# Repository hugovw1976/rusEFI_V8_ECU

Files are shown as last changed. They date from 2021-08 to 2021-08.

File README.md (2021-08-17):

# rusEFI_V8_ECU

- 8x 3A low-side drivers
- 4x 10A low_side drivers
- 8x 5v ignition or general purpose outputs (or 4 igniters/ 4general purpose otputs)
- One H-bridge for electronic throttle
- 10x Analog voltage inputs
- 4x Analog temperature (5v pullup) inputs
- 2x VR crank/cam/vehicle speed inputs
- 6x hall cam/crank or digital input (-2 if VR sensors used)
- Base on proteus board (intended for use with proteus firmware microcontroller, pin matched to correspond output)

rusEFI project: https://github.com/rusefi/rusefi
Proteus project: https://github.com/mck1117/proteus

Please do not use the gerber files, the board is not tested yet!
P&P file not tested on JLC PCB (Board is hand soldering)

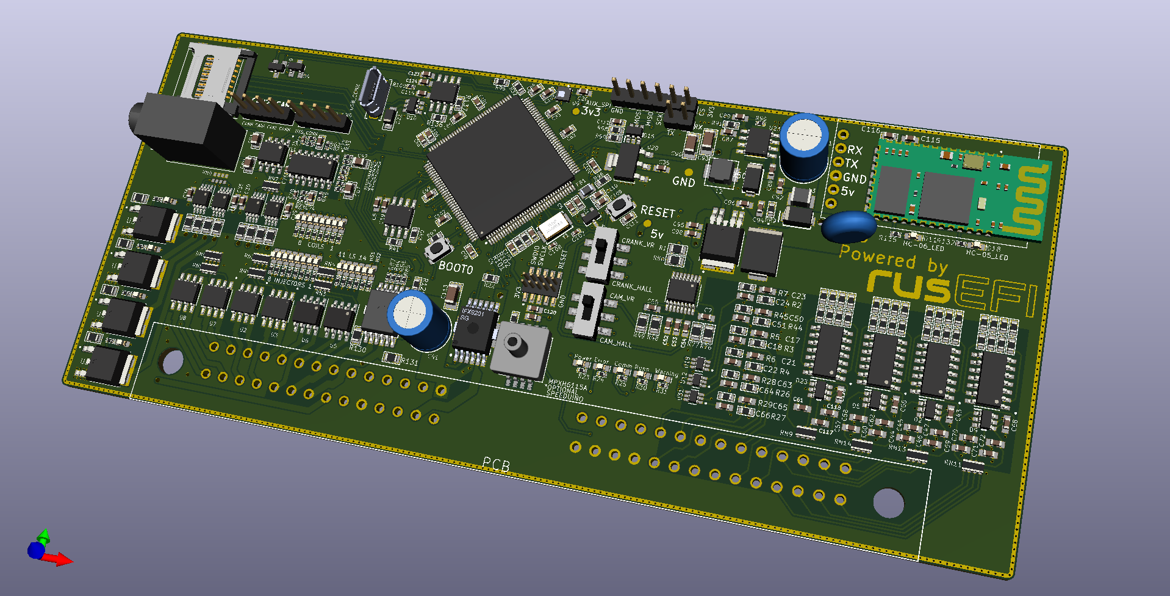
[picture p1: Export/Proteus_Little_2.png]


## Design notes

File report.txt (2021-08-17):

Cambiar footprint "D21" (from "Proteus_Little:SOD-123FL") to "Proteus_Little:SOD-123FL": OK
Cambiar footprint "D20" (from "Proteus_Little:SOD-123FL") to "Proteus_Little:SOD-123FL": OK
Cambiar footprint "D17" (from "Proteus_Little:SOD-123FL") to "Proteus_Little:SOD-123FL": OK
Cambiar footprint "D16" (from "Proteus_Little:SOD-123FL") to "Proteus_Little:SOD-123FL": OK

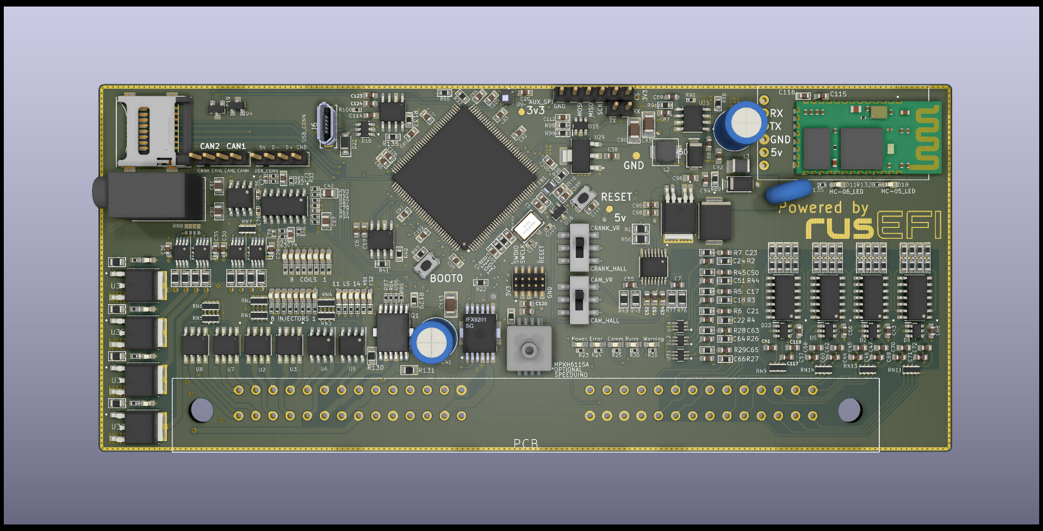
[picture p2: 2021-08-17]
Export/Proteus_Little_5.png

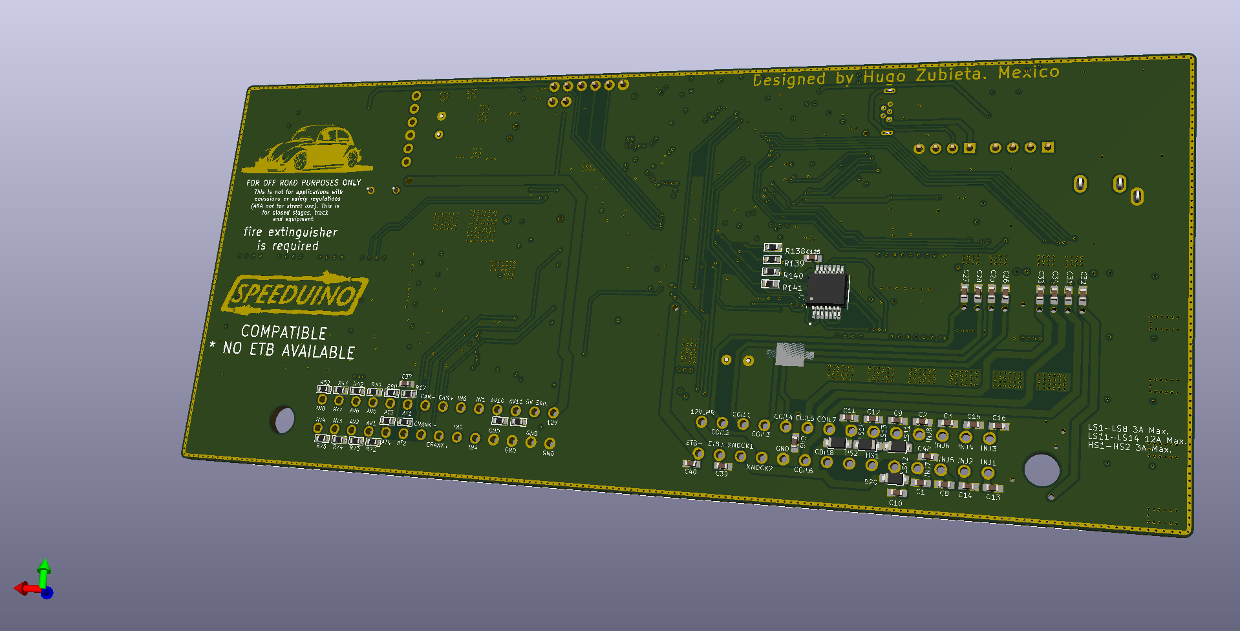
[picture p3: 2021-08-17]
Export/Proteus_Little_4.png

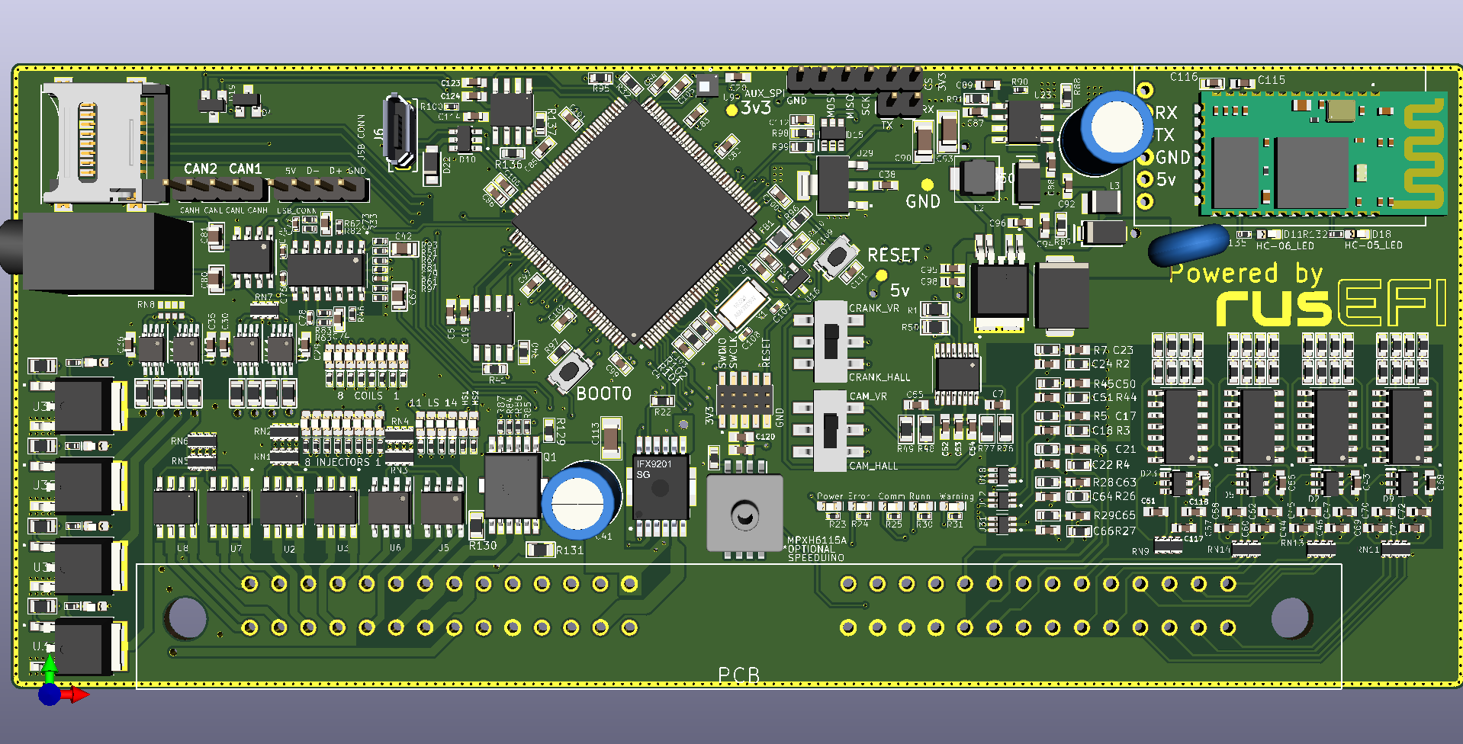
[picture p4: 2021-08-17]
Export/Proteus_Little_1.png

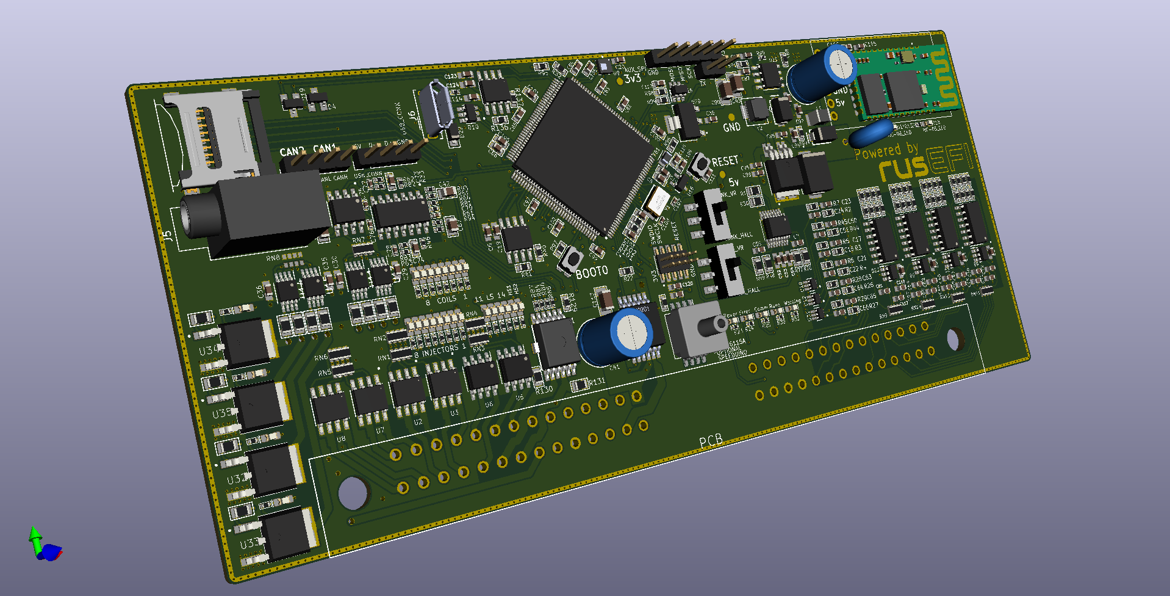
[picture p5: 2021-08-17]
Export/Proteus_Little_3.png

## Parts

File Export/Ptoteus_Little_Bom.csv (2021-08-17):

Qty | Value | Device | Package | LCSC PART # | MOUSER PART # | Parts
1 | B72530T6170K062 | VARISTOR-5 | R-5 | C693526 |  | R47
5 | 100K | SMD-RES-100K-1%-1/16W(0402) | R0402 | C25741 |  | R51, R61, R62, R63, R100
8 | 100R | SMD-RES-100R-5%-1/8W(0805) | R0805 | C441975 |  | R8, R9, R10, R11, R12, R13, R14, R15
4 | 10K | 4R-N0603-ARC | 0603-ARC | C29718 |  | RN9, RN11, RN13, RN14
2 | 10K | SMD-RES-10K-1%-1/16W(0402) | R0402 | C25744 |  | R84, R85
29 | 10K | SMD-RES-10K-1%-1/10W(0603) | R0603 | C323556 |  | R18, R19, R20, R21, R22, R40, R53, R54, R55, R56, R65, R67, R78, R79, R88, R96, R97, R98, R101, R102, R137, R138, R139, R140, R141, R147, R148, R149, R150
6 | 10K | SMD-RES-10K-1%-1/4W(0805) | R0805 | C161788 |  | R1, R48, R49, R50, R76, R77
2 | 15K | SMD-RES-15K-1%-1/16W(0402) | R0402 | C25756 |  | R86, R87
1 | 150R | SMD-RES-150-1%-1/4W(0805) | R0805 | C365244 |  | R129
2 | 4.7K | SMD-RES-4.7K-1%-1/4W(0805) | R0805 | C363267 |  | R130,R131
2 | 120R | SMD-RES-120R-5%-1/10W(0603) | R0603 | C22787 |  | R41, R136
8 | 1K | 4R-N0603-ARC | 0603-ARC | C20197 |  | RN1, RN2, RN3, RN4, RN5, RN6, RN7, RN8
3 | 12K | SMD-RES-12K-1%-1/16W(0402) | R0402 | C102781 |  | R33, R46, R90
1 | 1R | SMD-RES-1R-5%-1/10W(0603) | R0603 | C22936 |  | R89
8 | 2.2K | SMD-RES-2.2K-5%-1/10W(0603) | R0603 | C4190 |  | R2, R3, R4, R26, R27, R32, R44, R95
4 | 2.7K | SMD-RES-2.7K-1%-1/10W(0603) | R0603 | C328353 |  | R16, R17, R34, R80
2 | 22K | SMD-RES-22R-1%-1/16W(0402) | R0402 | C25768 |  | R64, R81
6 | 3.3K | SMD-RES-3.3K-1%-1/10W(0603) | R0603 | C22978 |  | R5, R6, R7, R28, R29, R45
33 | 330R | SMD-RES-330R-1%-1/16W(0402) | R0402 | C328315 |  | R23, R24, R25, R30, R31, R103, R104, R105, R106, R107, R108, R109, R110, R111, R112, R113, R114, R115, R116, R117, R118, R119, R120, R121, R122, R123, R124, R125, R126, R127, R128, R132, R135
4 | 330R | SMD-RES-330R-1%-1/8W(0805) | R0805 | C441945 |  | R1020, R1021, R1022, R1023
2 | 33K | SMD-RES-33K-1%-1/16W(0402) | R0402 | C25779 |  | R82, R83
11 | 470K | SMD-RES-470K-1%-1/10W(0603) | R0603 | C23178 |  | R39, R42, R43, R52, R66, R72, R73, R74, R75, R92, R133
2 | 470K | SMD-RES-470K-1%-1/16W(0402) | R0402 | C25790 |  | R93, R94
16 | 5.6K | SMD-RES-5.6K-1%-1/10W(0603) | R0603 | C114627 |  | R35, R36, R37, R38, R57, R58, R59, R60, R68, R69, R70, R71, R143, R144, R145, R146
1 | 68K | SMD-RES-68K-1%-1/10W(0603) | R0603 | C23231 |  | R91
1 | 82k | SMD-RES-82K-1%-1/10W(0603) | R0603 | C23254 |  | R99
8 | 1.0uF | 1uF ±10% 50V X7R 0603 | C0603 | C525334 |  | C6, C53, C92, C95, C96, C112, C116, C119, C120, C123
28 | 100nF | 100nF ±10% 50V X7R 0603 | C0603 | C14663 |  | C19, C20, C29, C30, C35, C36, C37, C44, C45, C46, C47, C52, C57, C58, C60, C61, C62, C69, C70, C71, C72, C88, C114, C115, C117, C118, C124, C125
38 | 10nF | 10nF ±10% 50V X7R 0603 | C0603 | C57112 |  | C1, C2, C3, C4, C5 C8, C9, C10, C11, C12, C13, C14, C15, C16, C25, C26, C27, C28, C31, C32, C33, C34, C39, C40, C48, C49, C54, C82, C83, C84, C85, C86,C87, C97, C99, C104, C109, C111
1 | 10nf | CERAMIC-10NF-50V-10%-X7R(0402) | C0402 | C15195 |  | C79
2 | 10uf | 10uF ±10% 16V X7R 0805 | C0805 | C95841 |  | C80, C81
3 | 10uf | 10uF ±10% 25V X7R 1206 | C1206 | C14860 |  | C90, C93, C113
14 | 1nF | 1nF ±10% 50V X7R 0603 | C0603 | C1588 |  | C7, C17, C18, C21, C22, C23, C24, C50, C51, C55, C63, C64, C65, C66
2 | 2.2uf | 2.2uF ±10% 25V X7R 0603 | C0603 | C99228 |  | C105, C106
1 | 22uf | 22uF ±20% 10V X5R 0603 | C0603 | C84419 |  | C98
1 | 270PF | 270pF ±10% 50V X7R 0603 | C0603 | C1608 |  | C89
2 | 3.3nf | 3.3nF ±10% 50V X7R 0805 | C0805 | C53175 |  | C42, C67
2 | 330PF 50V | 330pF ±5% 50V C0G 0402 | C0402 | C1535 |  | C77, C78
4 | 33nF | 33nF ±10% 50V X7R 0603 | C0603 | C21117 |  | C43, C56, C68, C118
2 | 33pf | 33pF ±5% 50V C0G 0402 | C0402 | C1562 |  | C107, C108
7 | 4.7uF | 4.7uF ±10% 35V X5R 0603 | C0603 | C329940 |  | C38, C94, C100, C101, C102, C103, C110
2 | 47PF | 47pF ±5% 50V C0G 0402 | C0402 | C1567 |  | C75, C76
2 | 680pf | 680pF ±10% 50V X7R 0603 | C0603 | C1630 |  | C73, C74
2 | 56uF | CPOL-USE3.5-8 | E3,5-8 |  | 667-EEH-AZF1H560 | C41, C91
1 | 10U | 10uH ±20% 3.2A 125mΩ SMD,5.2x5.4x3.0mm | 0503 | C139506 |  | L2
1 | 2.2U | 2.2uH ±5% 320mA 1Ω 1210 Inductors | 1210 | C36828 |  | L3
3 | 74HC2G17 | Dual non-inverting Schmitt trigger | SOT-363_SC-70-6 | C94189 |  | U12, U18, U31
1 | AMS1117-3.3 | AMS1117-3.3 | SOT-223 | C6186 |  | U29
2 | SMA_DIODE | Schottky Barrier Diodes 40V 3A 500mV @ 3A | SMA(DO-214AC) | C85098 |  | D12, D13
4 | DSS34 | DIODE_SOD-123FL | SOD-123FL | C511866 |  | D16, D17, D20, D21
1 | B5819W | Schottky Barrier Diodes | SOD-123FL | C8598 |  | D22
2 | PESD1CAN | PESD1CAN | SOT23 | C343993 |  | D4, D11
1 | SM15T33CA | BIDIRECTIONAL TVS | SMC(DO-214AB) | C133707 |  | D3
5 | SRV05-4.TCT | SRV05-4.TCT | SOT-23-6 | C85364 |  | D2, D5, D9, D15, D23
1 | USBLC6-2SC6 | SOT-23-6 Diodes | SOT-23-6 | C7519 |  | D10
1 | Yellow | LED-YELLOW0603 | LED-0603 | C84268 |  | D14
29 | Blue | LED-BLUE0603 | LED-0603 | C72041 |  | D8, D11, D18, D27, D28, D29, D30, D31, D32, D33, D34, D35, D36, D37, D38, D39, D40, D41, D42, D43, D44, D45, D46, D47, D48, D49, D50, D51, D52
1 | Red | LED-RED0603 | LED-0603 | C72044 |  | D1
2 | Green | LED-GREEN0603 | LED-0603 | C72043 |  | D6, D7
2 | K3-2235S-F1 | DPDT On-On SMD Toggle Switches | SW_JS202011SCQN | C223858 |  | S1, S3
2 | KMR221GLFS | SPST_SMD Tactile Switches | SMD 4.6x2.8 | C72443 |  | SW1, SW2
4 | ISL9V3040D3ST | Ignition IGBT | TO-252AA | C462128 |  | U32, U33, U34, U35
1 | LMR14020SDDAR | 40V 2A DC-DC Converters | SO PowerPAD-8 | C187824 |  | U23
1 | LPS25HBTR | Pressure Sensors | HLGA-10L | C87898 |  | U9
1 | MAX9926UAEE/V+ | Sensor Interface ICs | QSOP-16 | C2678421 |  | U19
1 | MCP6002T-E/MS | Low Power OpAmps | SOIC-8_150mil | C7377 |  | U$1
5 | MCP6004T | Low Power OpAmps | SOIC-14 | C7378 |  | U17, U22, U25, U28
4 | MIC4427YMM-TR | MIC4427YMM-TR | MSOP-8 | C144222 |  | U11, U13, U14, U15
1 | REF3033AIDBZR | Voltage References | SOT-23(SOT-23-3) | C36658 |  | U16
1 | STMICROELECTRONICS | STM32F429ZGT6 | LQFP-144_20x20x05P | C46525 |  | U20
1 | TLE4251DATMA1 | LDO Voltage Regulators | TO252-5 | C539669 |  | U21
1 | IFX9201SGAUMA1 | 6 A H-Bridge with SPI | SO-12 | C112633 |  | U10
2 | SN65HVD230DR | Transceiver CAN 1/1 1Mbps | SOIC-8_150mil | C12084 |  | U27, U30
1 | BTS5215L | MOSFET Gate Drivers | PG-DSO-12 | C386329 |  | Q1
4 | VNS3NV04PTR-E | MOSFET Gate Drivers | SO-8 | C146561 |  | U2, U3, U5, U6, U7, U8
1 | 8MHz ±10ppm 20pF 60Ω | SMD Crystal Resonators | SMD-5032_2P | C115962 |  | Y1
1 | FERRITE_BEAD | Ferrite Beads | F0805 | C1015 |  | FB1
1 | USB_CONN | U-D-M5DD-W-1 |  | C145795 |  | J6
1 | MPXH6115A | Pressure Sensor | SSOP-8 | ONLY FOR SPEEDUINO | 841-MPXH6115A6U | PS1
1 | SD_CONNECTOR | Connector microSD™ Memory Card 8 SMD |  | C125814 |  | J2
1 | AUDIO JACK 3.5MM | CUI DEVICES 3.5MM AUDIO JACK NO SWITCH |  |  | 490-SJ1-3533NG | J5
1 | 74HC125DB,112 | Quadruple Bus Buffer Gates | SSOP-14 | C507233 |  | U36
2 | VNLD5090TR-E | Low-side driver | SO-8 | C222209 |  | U5, U6

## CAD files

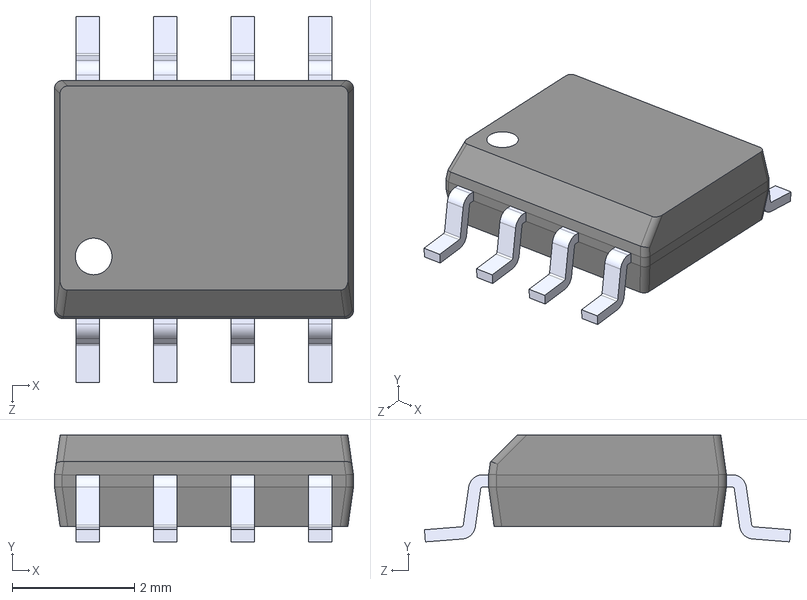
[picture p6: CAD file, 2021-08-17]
kicad-libraries-master/VNLD5090TR-E.step
4.90 x 1.75 x 6.00 mm

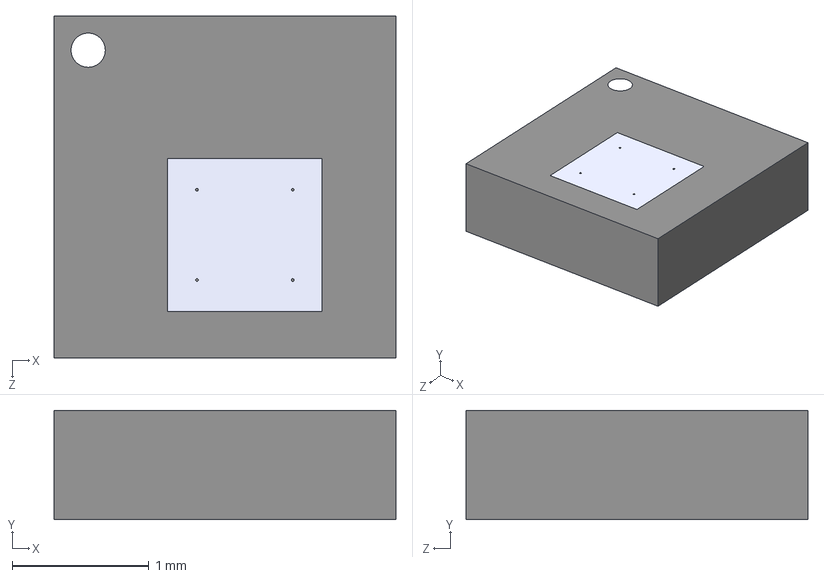
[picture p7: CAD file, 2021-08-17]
kicad-libraries-master/LPS25HBTR--3DModel-STEP-56544.STEP
2.50 x 0.8 x 2.50 mm

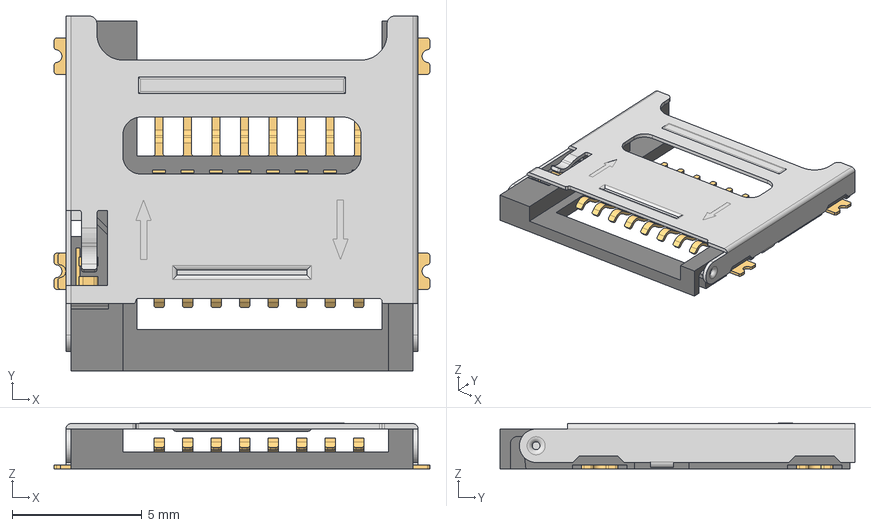
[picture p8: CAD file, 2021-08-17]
kicad-libraries-master/Micro_SD.stp
14.5 x 13.7 x 1.77 mm
693072010801_PIN x 8
693072010801_PATTE x 4
693072010801_CACHE
693072010801_PATTE_SPE

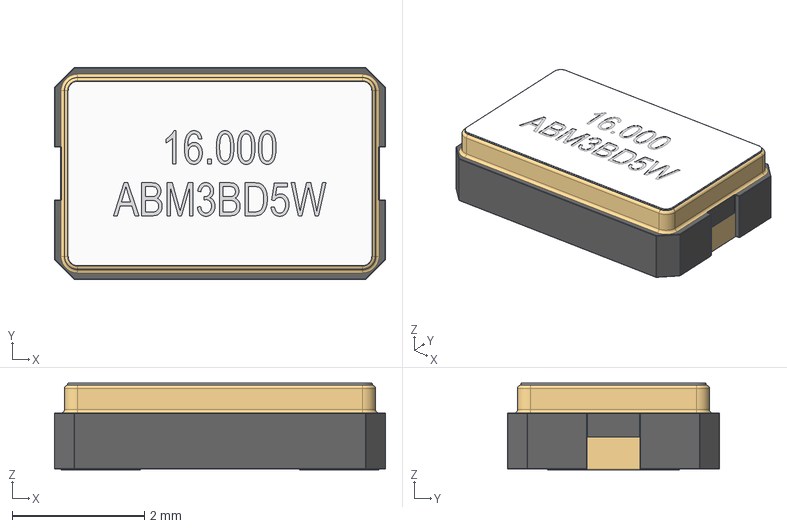
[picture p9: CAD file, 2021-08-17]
kicad-libraries-master/Crystal ABM3-16.000MHZ-B2-T.stp
5.00 x 3.20 x 1.31 mm

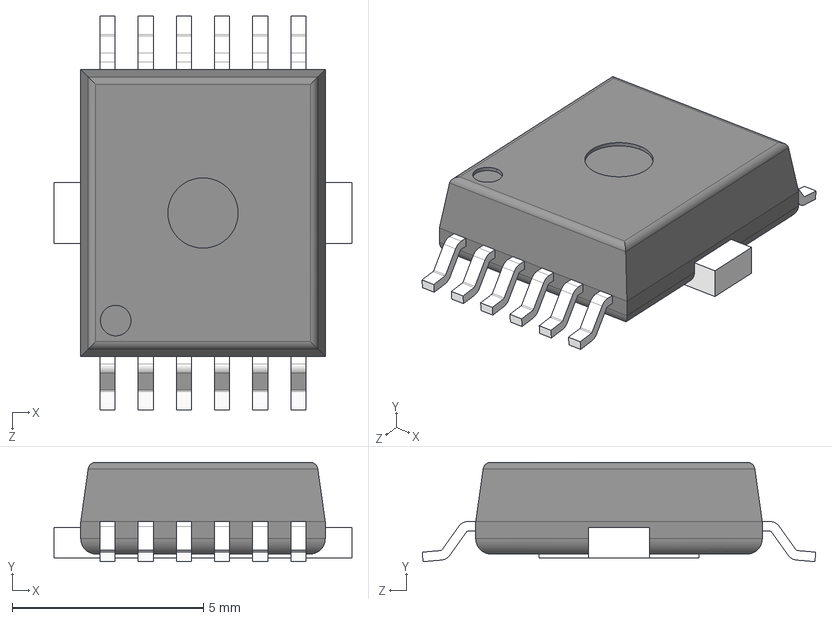
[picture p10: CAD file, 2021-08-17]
kicad-libraries-master/BTS5215L.step
7.80 x 2.60 x 10.3 mm

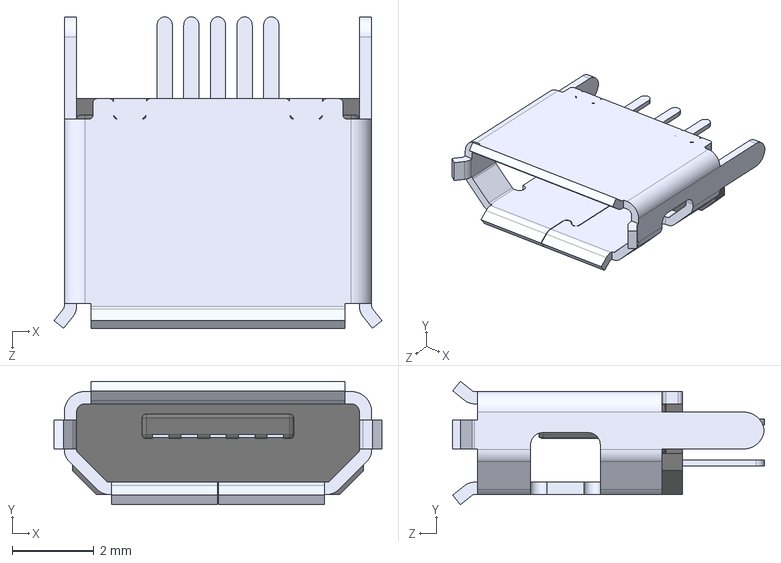
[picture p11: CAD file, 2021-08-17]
kicad-libraries-master/Micro usb_vetical.STEP
8.00 x 3.01 x 7.60 mm

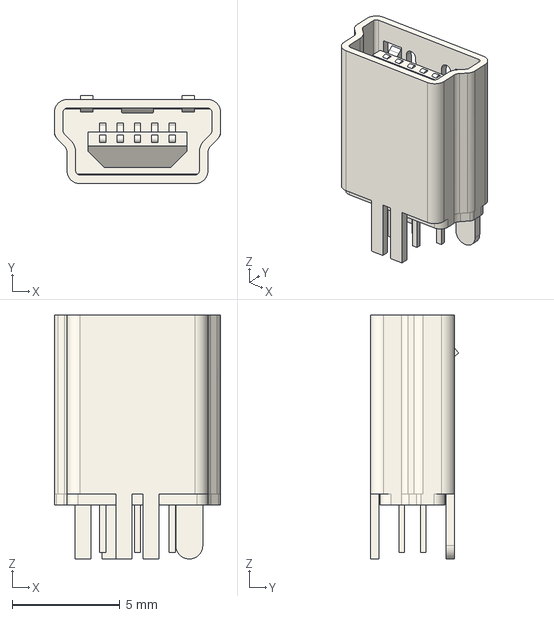
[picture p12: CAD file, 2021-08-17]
kicad-libraries-master/USB_Vert_C-1734753-1.step
7.70 x 4.09 x 11.3 mm

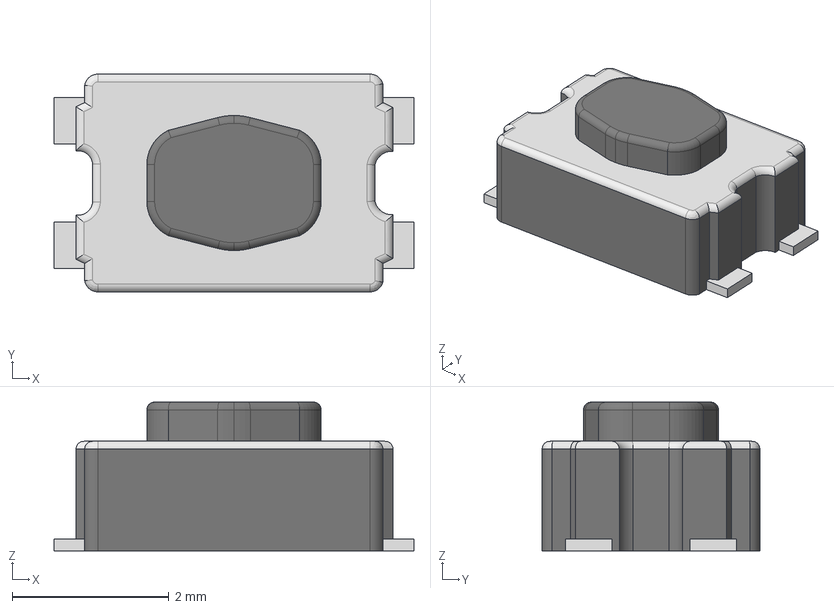
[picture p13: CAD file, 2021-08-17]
kicad-libraries-master/Switch_KMR621NG LFS.step
4.60 x 2.78 x 1.90 mm

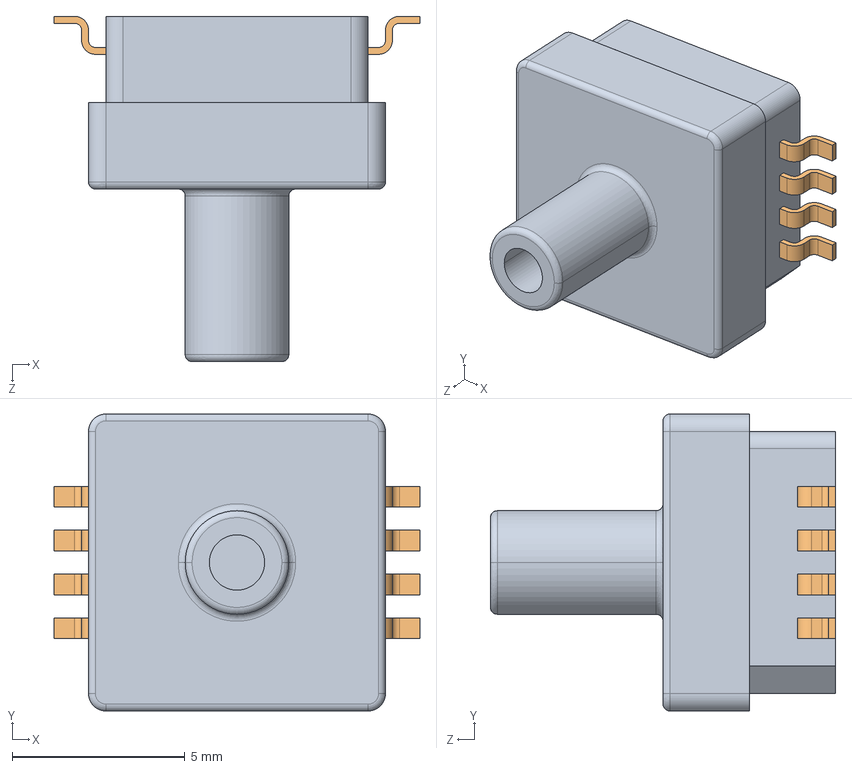
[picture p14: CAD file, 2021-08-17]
kicad-libraries-master/MPXH6115A.STEP
10.6 x 8.60 x 10.0 mm
Imported
Imported_2 x 8

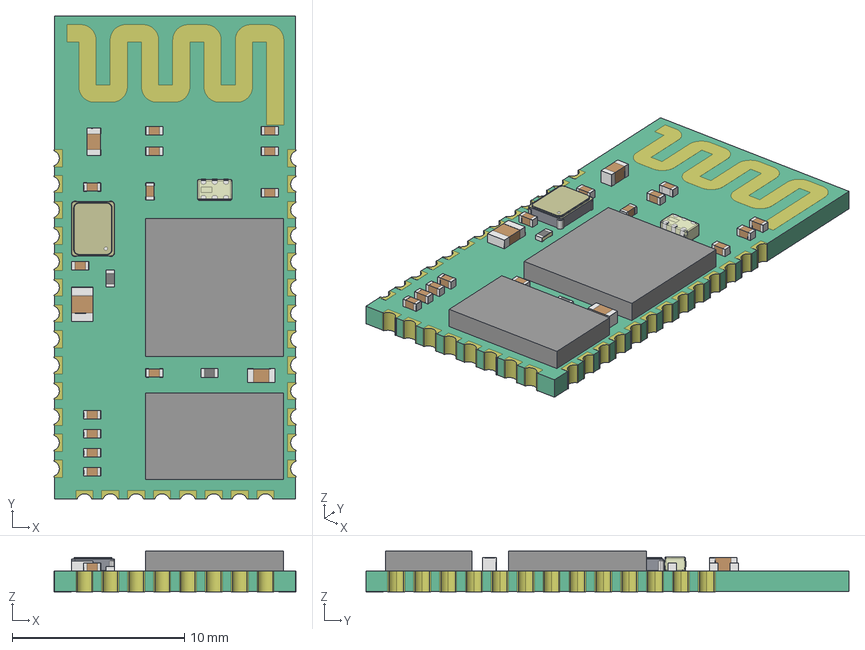
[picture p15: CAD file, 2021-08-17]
kicad-libraries-master/itead_hc-05.step
14.0 x 28.0 x 2.35 mm

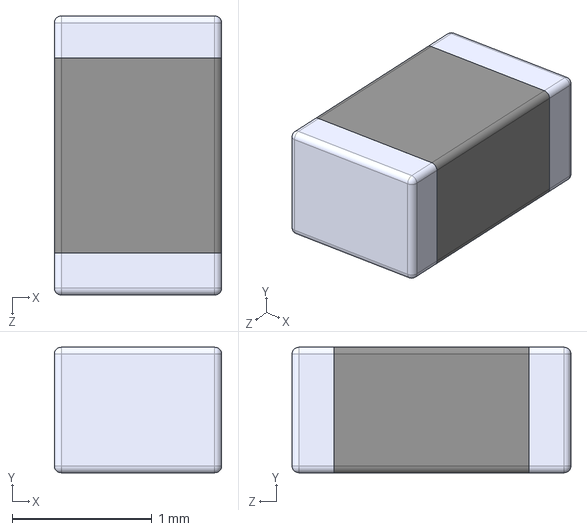
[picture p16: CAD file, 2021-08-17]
kicad-libraries-master/ferrite_bead_0805.STEP
1.20 x 0.9 x 2.00 mm

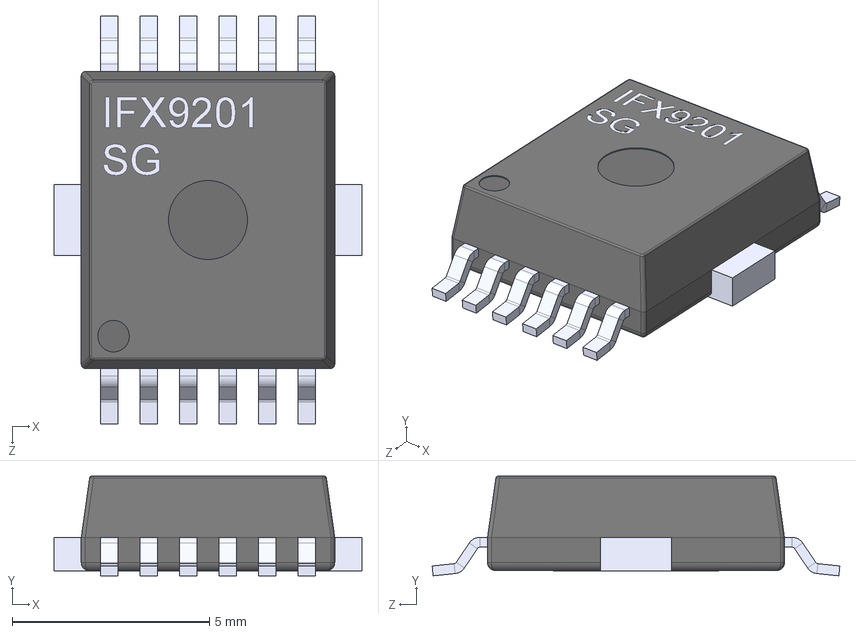
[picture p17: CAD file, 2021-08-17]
kicad-libraries-master/IFX9201SG-.STEP
7.80 x 2.52 x 10.3 mm

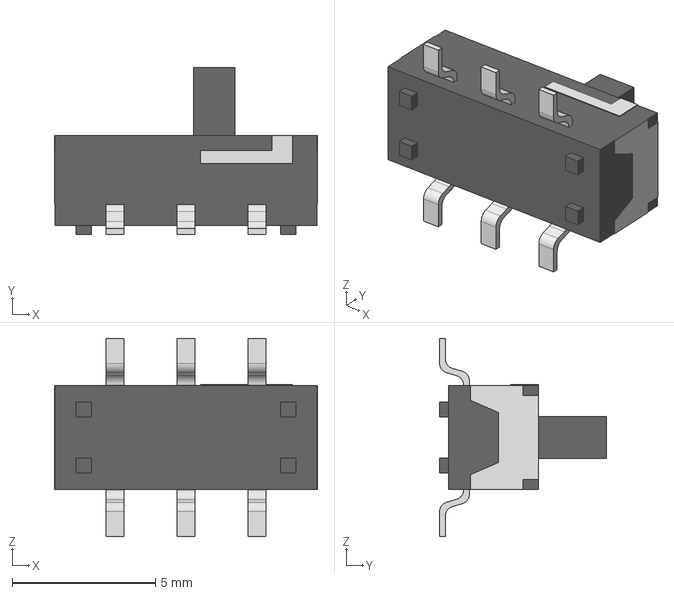
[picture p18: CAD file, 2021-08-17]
kicad-libraries-master/Selector Switch - MSS22D18.stp
9.17 x 5.82 x 6.91 mm

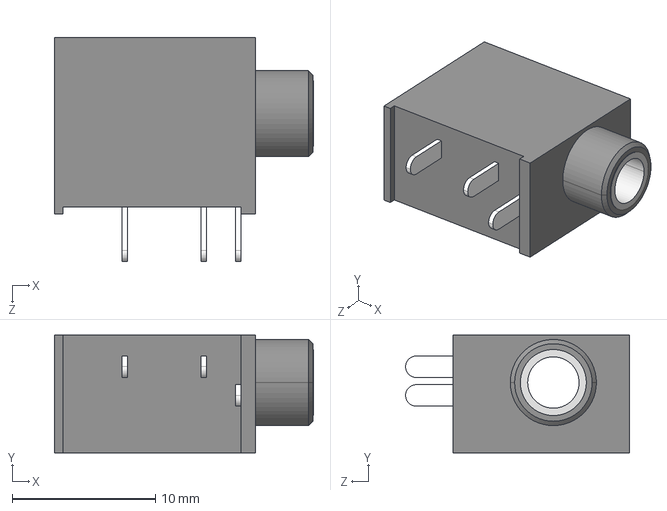
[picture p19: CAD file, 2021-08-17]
kicad-libraries-master/Audio_Jack_3.5mm.step
18.1 x 8.20 x 15.6 mm

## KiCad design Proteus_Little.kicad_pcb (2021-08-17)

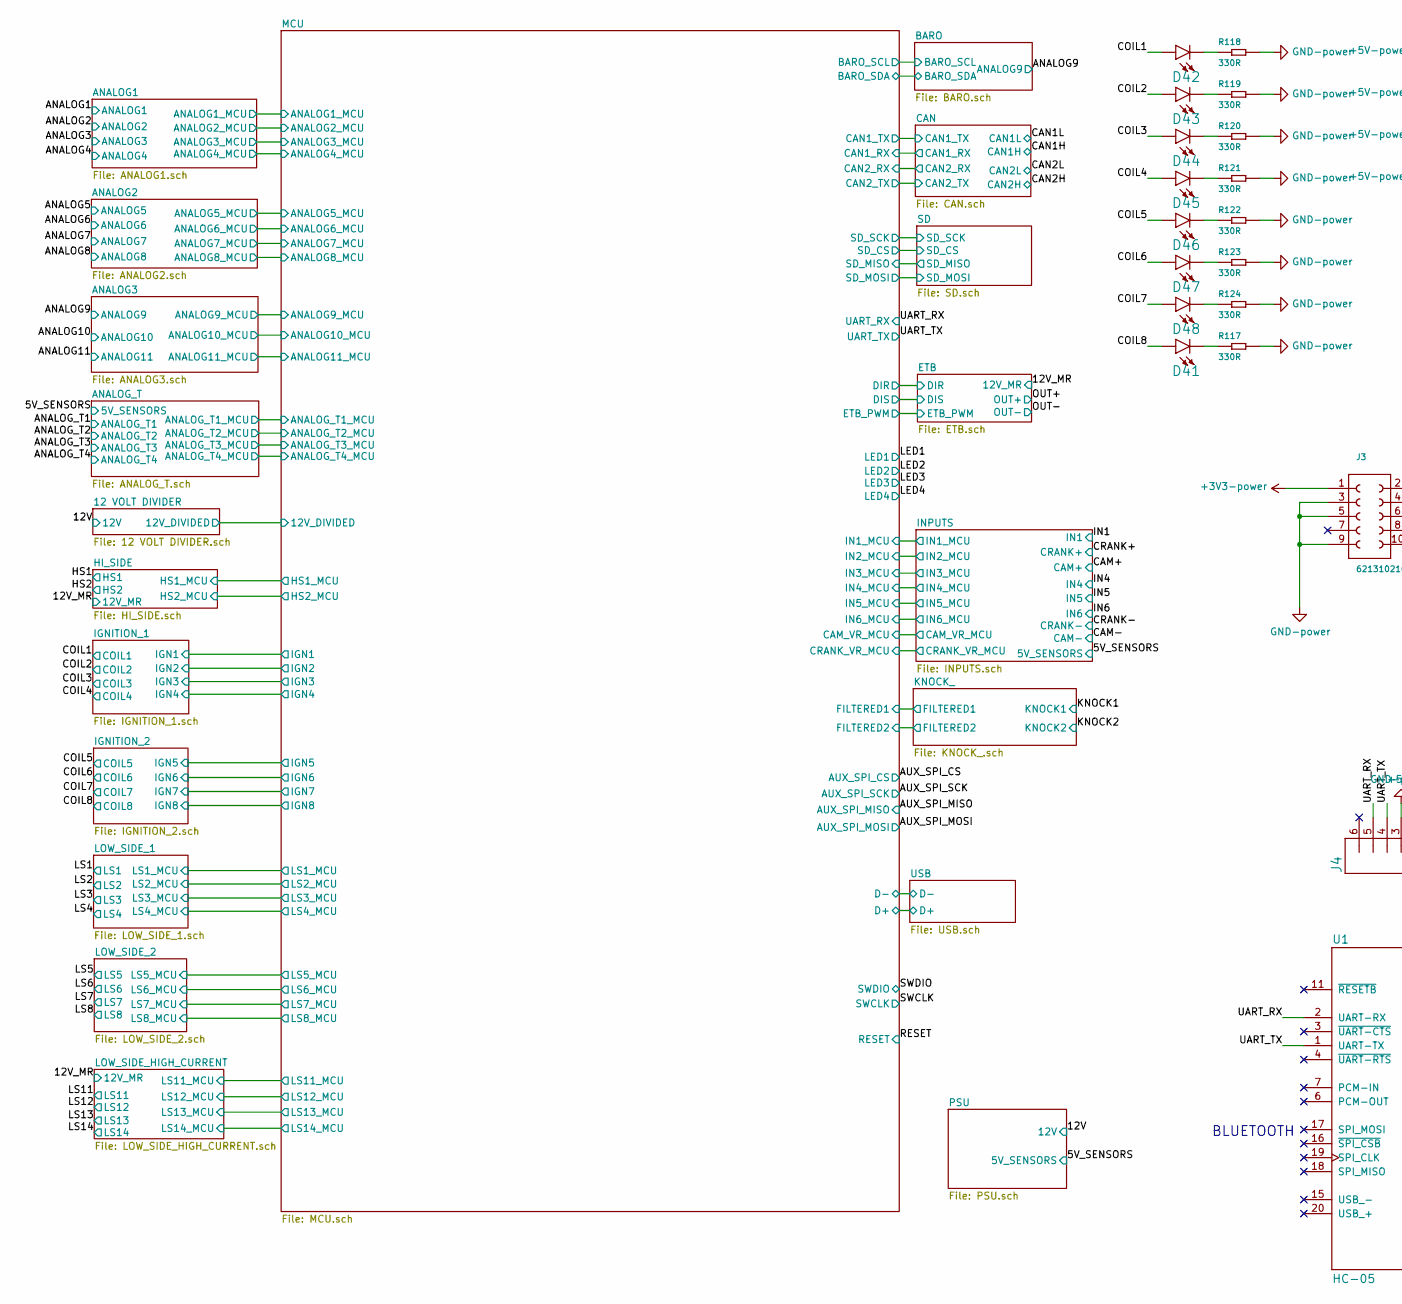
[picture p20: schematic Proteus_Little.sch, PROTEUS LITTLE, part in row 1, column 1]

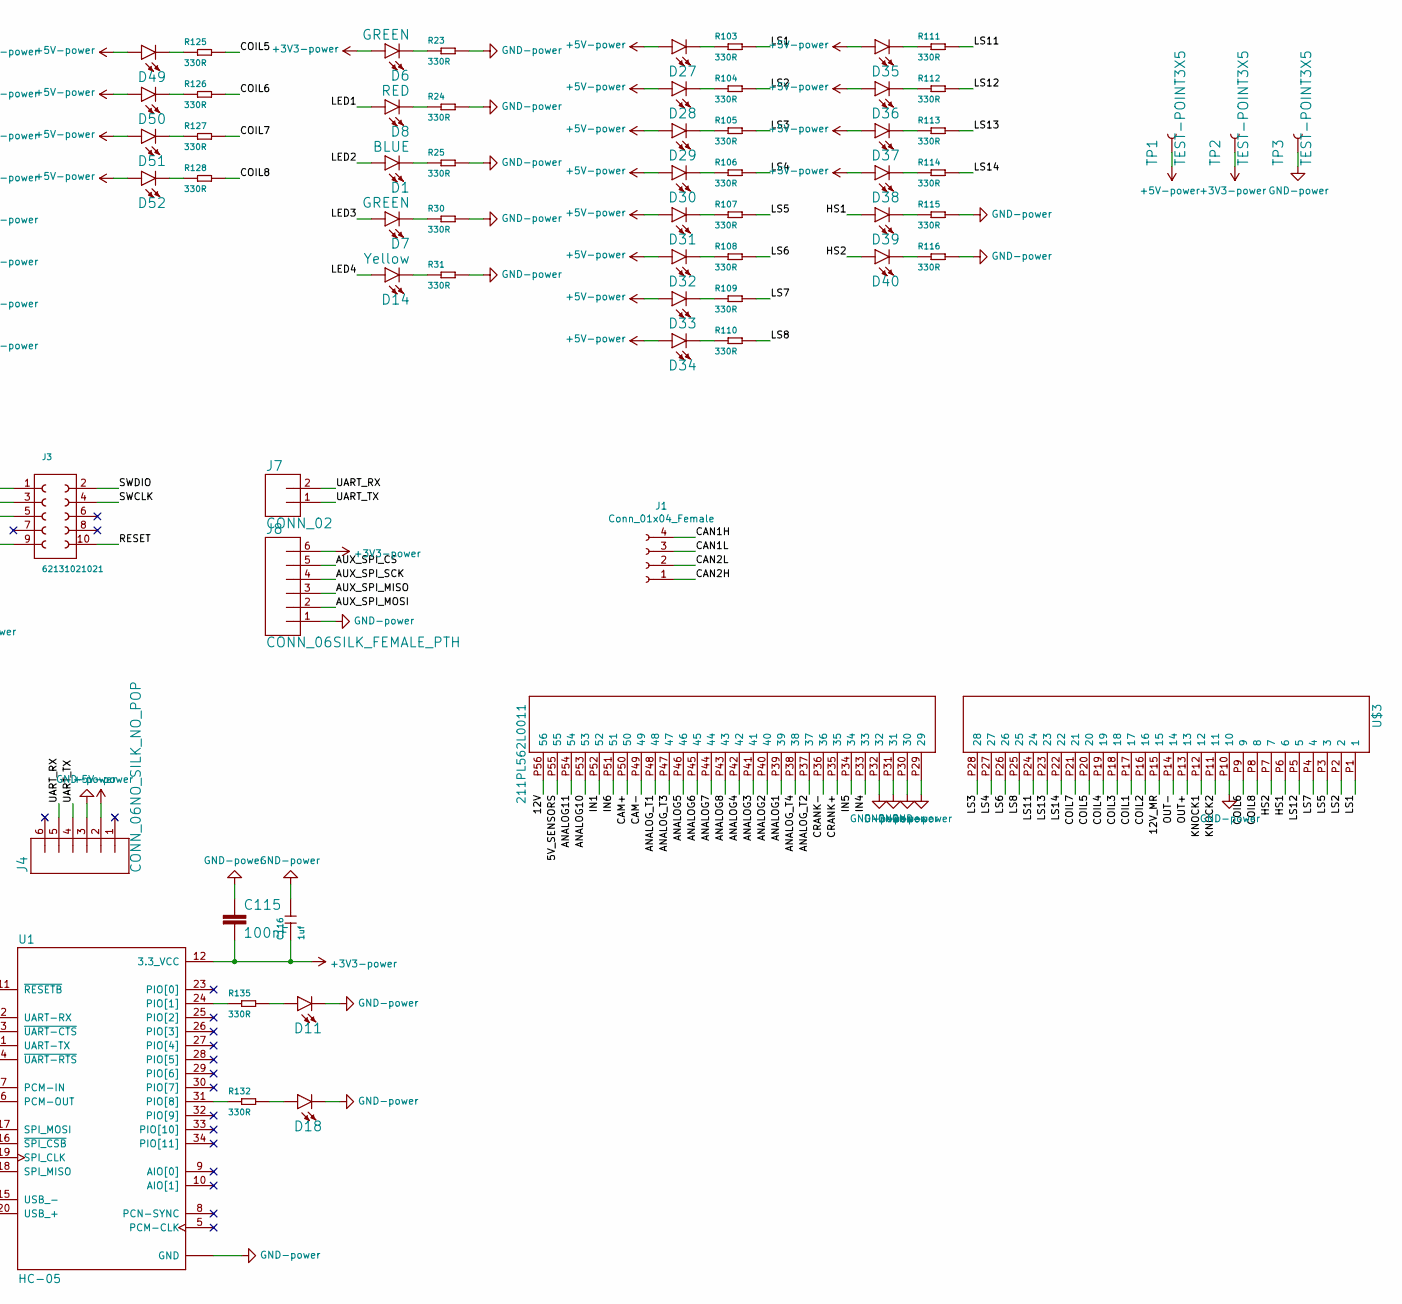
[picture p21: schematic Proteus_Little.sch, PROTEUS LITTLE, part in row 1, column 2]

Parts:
C115: 100nF; 0603
C116: 1uf; C0603
D1: BLUE; LED-0603
D6, D7: GREEN; LED-0603
D8, D11, D18, D27, D28, D29, D30, D31, D32, D33, D34, D35, D36, D37, D38, D39, D40, D41, D42, D43, D44, D45, D46, D47, D48, D49, D50, D51, D52: RED; LED-0603
D14: Yellow; LED-0603
J1: Conn_01x04_Female; PinHeader_1x04_P2.54mm_Vertical
J3: 62131021021
J4: CONN_06NO_SILK_NO_POP; 1X06_NO_SILK
J7: CONN_02; 1X02
J8: CONN_06SILK_FEMALE_PTH; 1X06
R23, R24, R25, R30, R31, R103, R104, R105, R106, R107, R108, R109, R110, R111, R112, R113, R114, R115, R116, R117, R118, R119, R120, R121, R122, R123, R124, R125, R126, R127, R128, R132, R135: 330R; R0402
TP1, TP2, TP3: TEST-POINT3X5; PAD.03X.05
U1: HC-05; XCVR_HC-05
U$3: 211PL562L0011; 211PL562L0011_2

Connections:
+3V3: C115.2, C116.1, D6.A, J3.1, J8.6, TP2.P$1, U1.12 (3.3_VCC); also elsewhere on the board
+5V: D27.A, D28.A, D29.A, D30.A, D31.A, D32.A, D33.A, D34.A, D35.A, D36.A, D37.A, D38.A, D49.A, D50.A, D51.A, D52.A, J4.2, TP1.P$1; also elsewhere on the board
/5V_SENSORS: U$3.P55 (55); also elsewhere on the board
/12V: U$3.P56 (56); also elsewhere on the board
/12V_MR: U$3.P15 (15); also elsewhere on the board
/ANALOG1: U$3.P39 (39); also elsewhere on the board
/ANALOG2: U$3.P40 (40); also elsewhere on the board
/ANALOG3: U$3.P41 (41); also elsewhere on the board
/ANALOG4: U$3.P42 (42); also elsewhere on the board
/ANALOG5: U$3.P46 (46); also elsewhere on the board
/ANALOG6: U$3.P45 (45); also elsewhere on the board
/ANALOG7: U$3.P44 (44); also elsewhere on the board
/ANALOG8: U$3.P43 (43); also elsewhere on the board
/ANALOG10: U$3.P53 (53); also elsewhere on the board
/ANALOG11: U$3.P54 (54); also elsewhere on the board
/ANALOG_T1: U$3.P48 (48); also elsewhere on the board
/ANALOG_T2: U$3.P37 (37); also elsewhere on the board
/ANALOG_T3: U$3.P47 (47); also elsewhere on the board
/ANALOG_T4: U$3.P38 (38); also elsewhere on the board
/AUX_SPI_CS: J8.5; also elsewhere on the board
/AUX_SPI_MISO: J8.3; also elsewhere on the board
/AUX_SPI_MOSI: J8.2; also elsewhere on the board
/AUX_SPI_SCK: J8.4; also elsewhere on the board
/CAM+: U$3.P50 (50); also elsewhere on the board
/CAM-: U$3.P49 (49); also elsewhere on the board
/CAN1H: J1.4; also elsewhere on the board
/CAN1L: J1.3; also elsewhere on the board
/CAN2H: J1.1; also elsewhere on the board
/CAN2L: J1.2; also elsewhere on the board
/COIL1: D42.A, U$3.P17 (17); also elsewhere on the board
/COIL2: D43.A, U$3.P16 (16); also elsewhere on the board
/COIL3: D44.A, U$3.P18 (18); also elsewhere on the board
/COIL4: D45.A, U$3.P19 (19); also elsewhere on the board
/COIL5: D46.A, R125.2, U$3.P20 (20); also elsewhere on the board
/COIL6: D47.A, R126.2, U$3.P9 (9); also elsewhere on the board
/COIL7: D48.A, R127.2, U$3.P21 (21); also elsewhere on the board
/COIL8: D41.A, R128.2, U$3.P8 (8); also elsewhere on the board
/CRANK+: U$3.P35 (35); also elsewhere on the board
/CRANK-: U$3.P36 (36); also elsewhere on the board
/HS1: D39.A, U$3.P6 (6); also elsewhere on the board
/HS2: D40.A, U$3.P7 (7); also elsewhere on the board
/IN1: U$3.P52 (52); also elsewhere on the board
/IN4: U$3.P33 (33); also elsewhere on the board
/IN5: U$3.P34 (34); also elsewhere on the board
/IN6: U$3.P51 (51); also elsewhere on the board
/KNOCK1: U$3.P12 (12); also elsewhere on the board
/KNOCK2: U$3.P11 (11); also elsewhere on the board
/LED1: D8.A; also elsewhere on the board
/LED2: D1.A; also elsewhere on the board
/LED3: D7.A; also elsewhere on the board
/LED4: D14.A; also elsewhere on the board
/LS1: R103.2, U$3.P1 (1); also elsewhere on the board
/LS2: R104.2, U$3.P2 (2); also elsewhere on the board
/LS3: R105.2, U$3.P28 (28); also elsewhere on the board
/LS4: R106.2, U$3.P27 (27); also elsewhere on the board
/LS5: R107.2, U$3.P3 (3); also elsewhere on the board
/LS6: R108.2, U$3.P26 (26); also elsewhere on the board
/LS7: R109.2, U$3.P4 (4); also elsewhere on the board
/LS8: R110.2, U$3.P25 (25); also elsewhere on the board
/LS11: R111.2, U$3.P24 (24); also elsewhere on the board
/LS12: R112.2, U$3.P5 (5); also elsewhere on the board
/LS13: R113.2, U$3.P23 (23); also elsewhere on the board
/LS14: R114.2, U$3.P22 (22); also elsewhere on the board
/OUT+: U$3.P13 (13); also elsewhere on the board
/OUT-: U$3.P14 (14); also elsewhere on the board
/RESET: J3.10; also elsewhere on the board
/SWCLK: J3.4; also elsewhere on the board
/SWDIO: J3.2; also elsewhere on the board
/UART_RX: J4.5, J7.2, U1.2 (UART-RX); also elsewhere on the board
/UART_TX: J4.4, J7.1, U1.1 (UART-TX); also elsewhere on the board
GND: C115.1, C116.2, D11.C, D18.C, J3.3, J3.5, J3.9, J4.3, J8.1, R23.2, R24.2, R25.2, R30.2, R31.2, R115.2, R116.2, R117.2, R118.2, R119.2, R120.2, R121.2, R122.2, R123.2, R124.2, TP3.P$1, U1.13 (GND), U1.21 (GND), U1.22 (GND), U$3.P10 (10), U$3.P29 (29), U$3.P30 (30), U$3.P31 (31), U$3.P32 (32); also elsewhere on the board
unnamed: D1.C, R25.1
unnamed: D6.C, R23.1
unnamed: D7.C, R30.1
unnamed: D8.C, R24.1
unnamed: D11.A, R135.2
unnamed: D14.C, R31.1
unnamed: D18.A, R132.2
unnamed: D27.C, R103.1
unnamed: D28.C, R104.1
unnamed: D29.C, R105.1
unnamed: D30.C, R106.1
unnamed: D31.C, R107.1
unnamed: D32.C, R108.1
unnamed: D33.C, R109.1
unnamed: D34.C, R110.1
unnamed: D35.C, R111.1
unnamed: D36.C, R112.1
unnamed: D37.C, R113.1
unnamed: D38.C, R114.1
unnamed: D39.C, R115.1
unnamed: D40.C, R116.1
unnamed: D41.C, R117.1
unnamed: D42.C, R118.1
unnamed: D43.C, R119.1
unnamed: D44.C, R120.1
unnamed: D45.C, R121.1
unnamed: D46.C, R122.1
unnamed: D47.C, R123.1
unnamed: D48.C, R124.1
unnamed: D49.C, R125.1
unnamed: D50.C, R126.1
unnamed: D51.C, R127.1
unnamed: D52.C, R128.1
unnamed: R132.1, U1.31 (PIO[8])
unnamed: R135.1, U1.24 (PIO[1])

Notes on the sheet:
BLUETOOTH

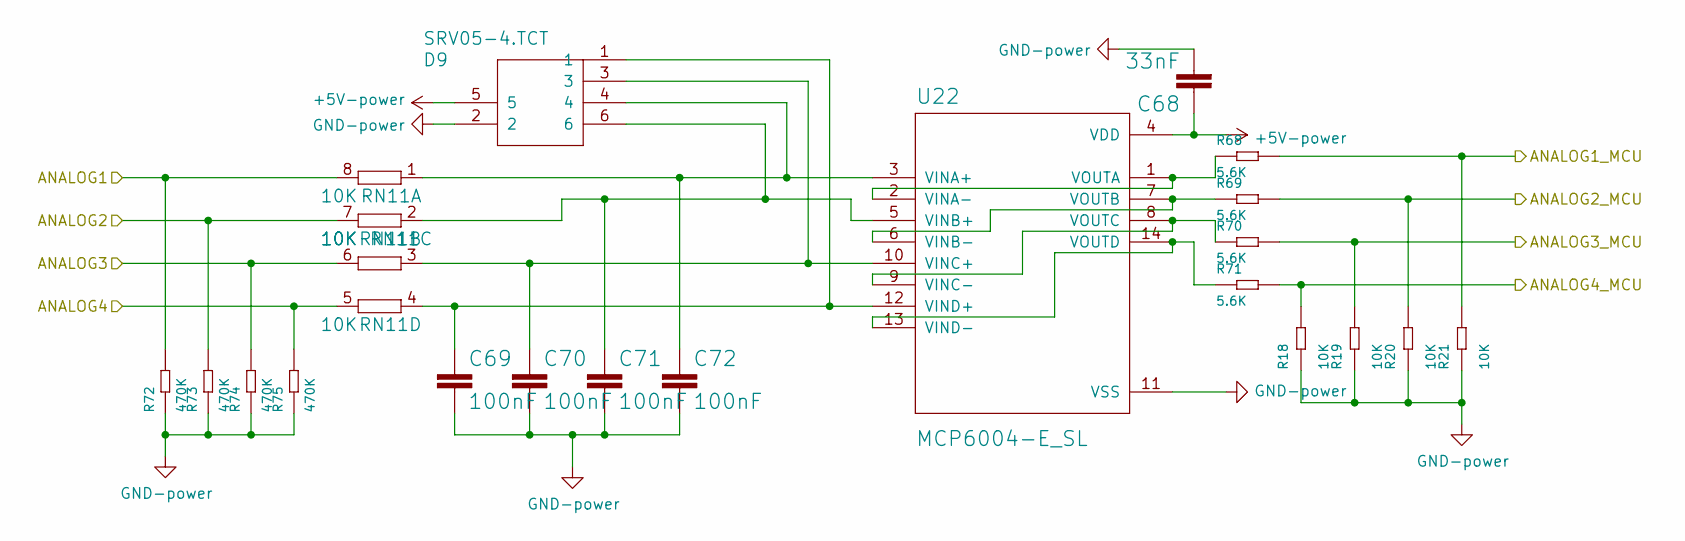
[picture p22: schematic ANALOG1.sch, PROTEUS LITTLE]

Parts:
C68: 33nF; 0603
C69, C70, C71, C72: 100nF; 0603
D9: SRV05-4.TCT; SOT95P280X145-6N
R18, R19, R20, R21: 10K; R0603
R68, R69, R70, R71: 5.6K; R0603
R72, R73, R74, R75: 470K; R0603
RN11: 10K; 0603-ARC
U22: MCP6004-E_SL; SOIC127P600X175-14N

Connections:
+5V: C68.1, D9.5, U22.4 (VDD); also elsewhere on the board
/ANALOG1: R72.2, RN11.8 (2); also elsewhere on the board
/ANALOG1/ANALOG1_MCU: R21.2, R68.2; also elsewhere on the board
/ANALOG1/ANALOG2_MCU: R20.2, R69.2; also elsewhere on the board
/ANALOG1/ANALOG3_MCU: R19.2, R70.2; also elsewhere on the board
/ANALOG1/ANALOG4_MCU: R18.2, R71.2; also elsewhere on the board
/ANALOG2: R73.2, RN11.7 (2); also elsewhere on the board
/ANALOG3: R74.2, RN11.6 (2); also elsewhere on the board
/ANALOG4: R75.2, RN11.5 (2); also elsewhere on the board
GND: C68.2, C69.2, C70.2, C71.2, C72.2, D9.2, R18.1, R19.1, R20.1, R21.1, R72.1, R73.1, R74.1, R75.1, U22.11 (VSS); also elsewhere on the board
unnamed: C69.1, D9.1, RN11.4 (1), U22.12 (VIND+)
unnamed: C70.1, D9.3, RN11.3 (1), U22.10 (VINC+)
unnamed: C71.1, D9.6, RN11.2 (1), U22.5 (VINB+)
unnamed: C72.1, D9.4, RN11.1, U22.3 (VINA+)
unnamed: R68.1, U22.1 (VOUTA), U22.2 (VINA-)
unnamed: R69.1, U22.6 (VINB-), U22.7 (VOUTB)
unnamed: R70.1, U22.8 (VOUTC), U22.9 (VINC-)
unnamed: R71.1, U22.13 (VIND-), U22.14 (VOUTD)

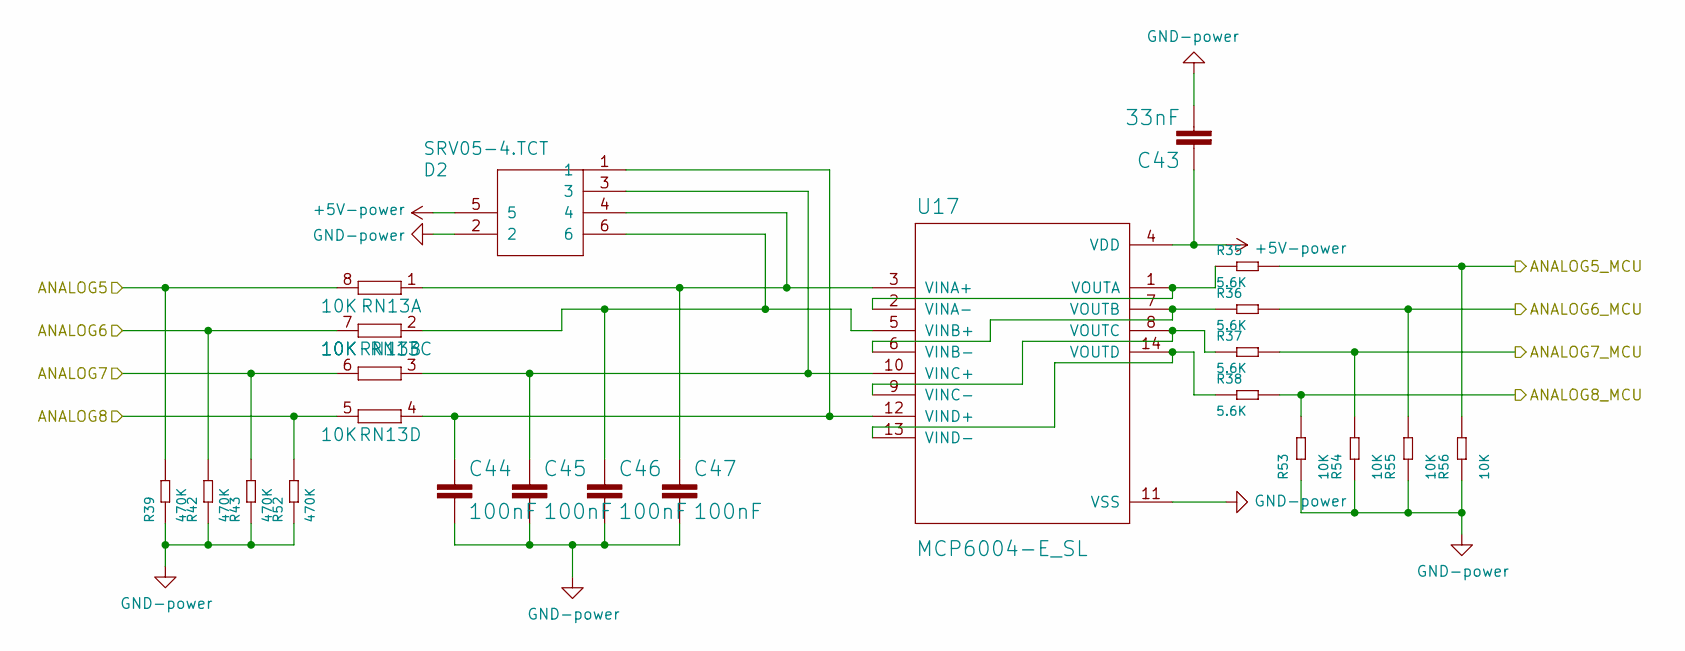
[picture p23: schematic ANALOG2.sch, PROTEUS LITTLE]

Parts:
C43: 33nF; 0603
C44, C45, C46, C47: 100nF; 0603
D2: SRV05-4.TCT; SOT95P280X145-6N
R35, R36, R37, R38: 5.6K; R0603
R39, R42, R43, R52: 470K; R0603
R53, R54, R55, R56: 10K; R0603
RN13: 10K; 0603-ARC
U17: MCP6004-E_SL; SOIC127P600X175-14N

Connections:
+5V: C43.1, D2.5, U17.4 (VDD); also elsewhere on the board
/ANALOG2/ANALOG5_MCU: R35.2, R56.2; also elsewhere on the board
/ANALOG2/ANALOG6_MCU: R36.2, R55.2; also elsewhere on the board
/ANALOG2/ANALOG7_MCU: R37.2, R54.2; also elsewhere on the board
/ANALOG2/ANALOG8_MCU: R38.2, R53.2; also elsewhere on the board
/ANALOG5: R39.2, RN13.8 (2); also elsewhere on the board
/ANALOG6: R42.2, RN13.7 (2); also elsewhere on the board
/ANALOG7: R43.2, RN13.6 (2); also elsewhere on the board
/ANALOG8: R52.2, RN13.5 (2); also elsewhere on the board
GND: C43.2, C44.2, C45.2, C46.2, C47.2, D2.2, R39.1, R42.1, R43.1, R52.1, R53.1, R54.1, R55.1, R56.1, U17.11 (VSS); also elsewhere on the board
unnamed: C44.1, D2.1, RN13.4 (1), U17.12 (VIND+)
unnamed: C45.1, D2.3, RN13.3 (1), U17.10 (VINC+)
unnamed: C46.1, D2.6, RN13.2 (1), U17.5 (VINB+)
unnamed: C47.1, D2.4, RN13.1, U17.3 (VINA+)
unnamed: R35.1, U17.1 (VOUTA), U17.2 (VINA-)
unnamed: R36.1, U17.6 (VINB-), U17.7 (VOUTB)
unnamed: R37.1, U17.8 (VOUTC), U17.9 (VINC-)
unnamed: R38.1, U17.13 (VIND-), U17.14 (VOUTD)

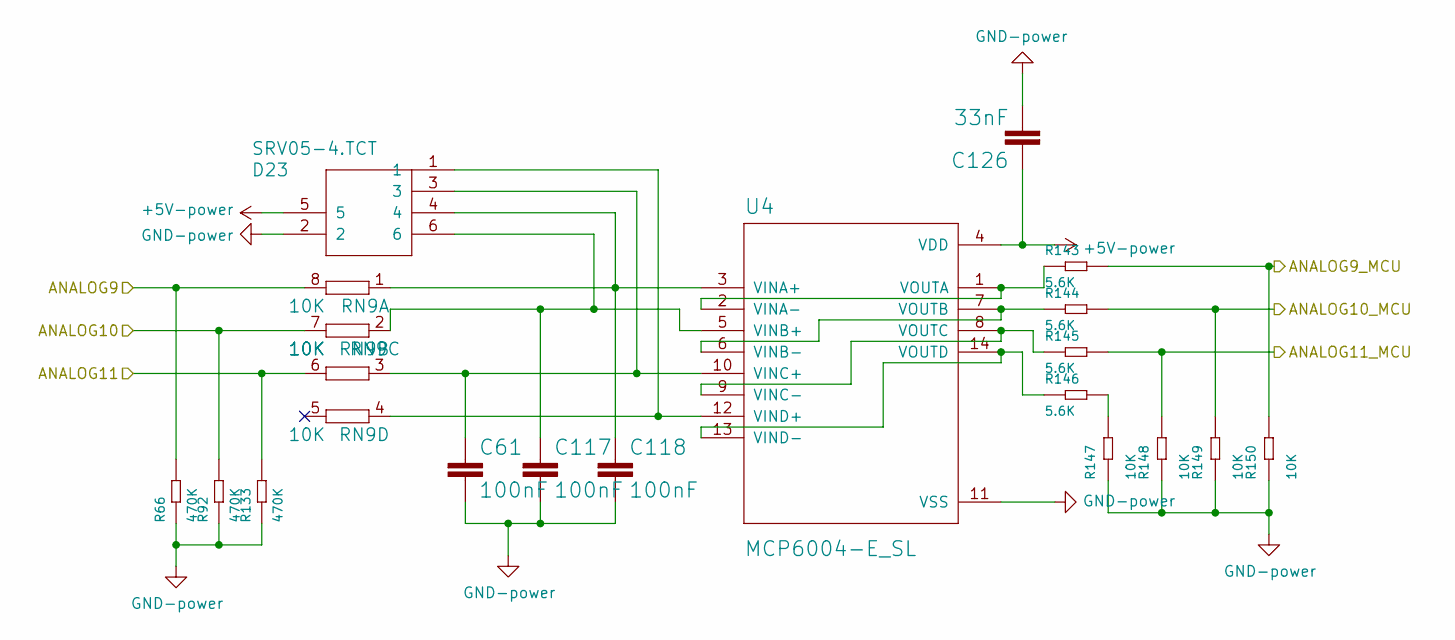
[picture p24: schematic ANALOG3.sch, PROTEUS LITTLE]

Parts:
C61, C117, C118: 100nF; 0603
C126: 33nF; 0603
D23: SRV05-4.TCT; SOT95P280X145-6N
R66, R92, R133: 470K; R0603
R143, R144, R145, R146: 5.6K; R0603
R147, R148, R149, R150: 10K; R0603
RN9: 10K; 0603-ARC
U4: MCP6004-E_SL; SOIC127P600X175-14N

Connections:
+5V: C126.1, D23.5, U4.4 (VDD); also elsewhere on the board
/ANALOG3/ANALOG9_MCU: R143.2, R150.2; also elsewhere on the board
/ANALOG3/ANALOG10_MCU: R144.2, R149.2; also elsewhere on the board
/ANALOG3/ANALOG11_MCU: R145.2, R148.2; also elsewhere on the board
/ANALOG9: R66.2, RN9.8 (2); also elsewhere on the board
/ANALOG10: R92.2, RN9.7 (2); also elsewhere on the board
/ANALOG11: R133.2, RN9.6 (2); also elsewhere on the board
GND: C61.2, C117.2, C118.2, C126.2, D23.2, R66.1, R92.1, R133.1, R147.1, R148.1, R149.1, R150.1, U4.11 (VSS); also elsewhere on the board
unnamed: C61.1, D23.3, RN9.3 (1), U4.10 (VINC+)
unnamed: C117.1, D23.6, RN9.2 (1), U4.5 (VINB+)
unnamed: C118.1, D23.4, RN9.1, U4.3 (VINA+)
unnamed: D23.1, RN9.4 (1), U4.12 (VIND+)
unnamed: R143.1, U4.1 (VOUTA), U4.2 (VINA-)
unnamed: R144.1, U4.6 (VINB-), U4.7 (VOUTB)
unnamed: R145.1, U4.8 (VOUTC), U4.9 (VINC-)
unnamed: R146.1, U4.13 (VIND-), U4.14 (VOUTD)
unnamed: R146.2, R147.2

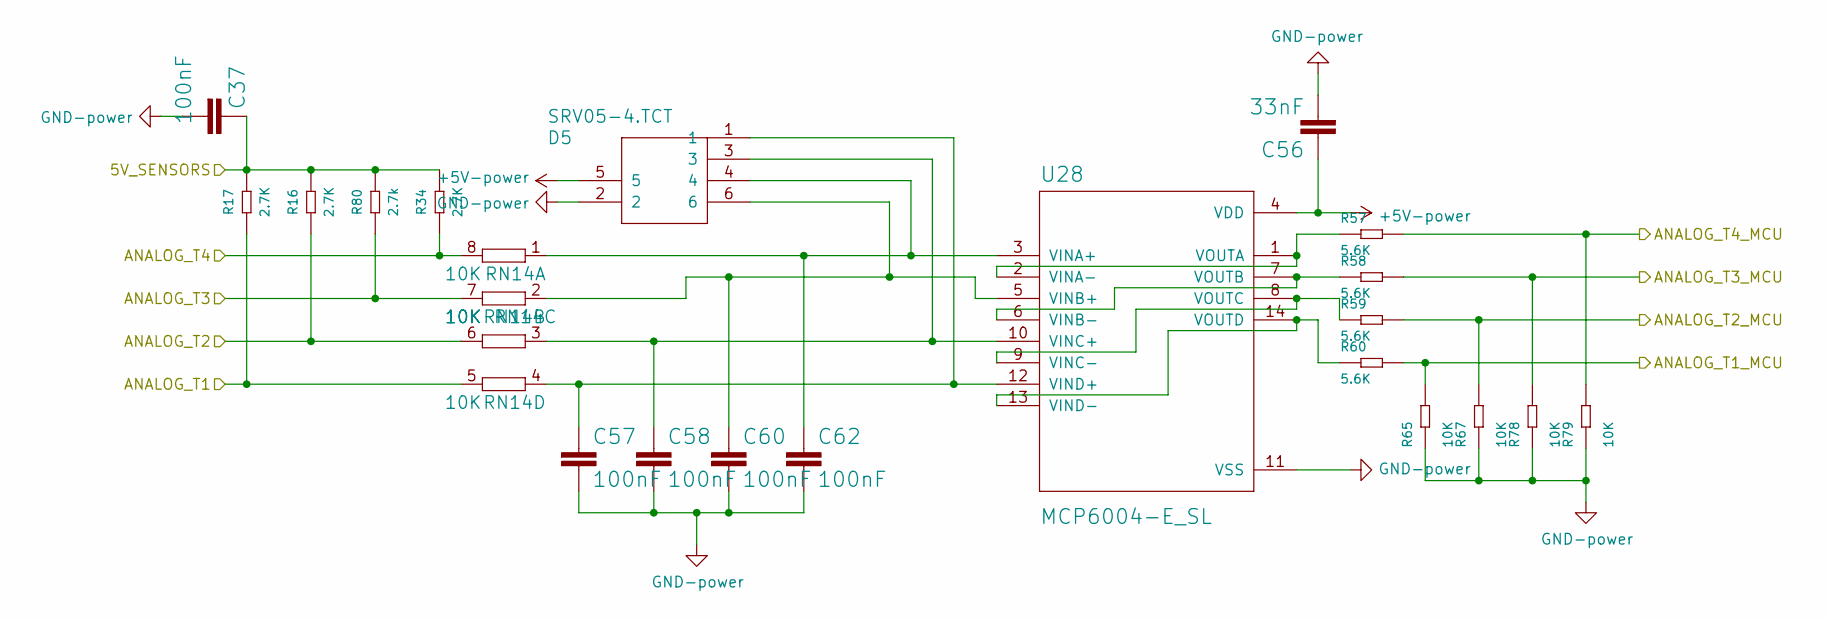
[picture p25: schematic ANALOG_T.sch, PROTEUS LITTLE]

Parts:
C37, C57, C58, C60, C62: 100nF; 0603
C56: 33nF; 0603
D5: SRV05-4.TCT; SOT95P280X145-6N
R16, R17, R34: 2.7K; R0603
R57, R58, R59, R60: 5.6K; R0603
R65, R67, R78, R79: 10K; R0603
R80: 2.7k; R0603
RN14: 10K; 0603-ARC
U28: MCP6004-E_SL; SOIC127P600X175-14N

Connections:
+5V: C56.1, D5.5, U28.4 (VDD); also elsewhere on the board
/5V_SENSORS: C37.1, R16.2, R17.2, R34.2, R80.2; also elsewhere on the board
/ANALOG_T1: R17.1, RN14.5 (2); also elsewhere on the board
/ANALOG_T2: R16.1, RN14.6 (2); also elsewhere on the board
/ANALOG_T3: R80.1, RN14.7 (2); also elsewhere on the board
/ANALOG_T4: R34.1, RN14.8 (2); also elsewhere on the board
/ANALOG_T/ANALOG_T1_MCU: R60.2, R65.2; also elsewhere on the board
/ANALOG_T/ANALOG_T2_MCU: R59.2, R67.2; also elsewhere on the board
/ANALOG_T/ANALOG_T3_MCU: R58.2, R78.2; also elsewhere on the board
/ANALOG_T/ANALOG_T4_MCU: R57.2, R79.2; also elsewhere on the board
GND: C37.2, C56.2, C57.2, C58.2, C60.2, C62.2, D5.2, R65.1, R67.1, R78.1, R79.1, U28.11 (VSS); also elsewhere on the board
unnamed: C57.1, D5.1, RN14.4 (1), U28.12 (VIND+)
unnamed: C58.1, D5.3, RN14.3 (1), U28.10 (VINC+)
unnamed: C60.1, D5.6, RN14.2 (1), U28.5 (VINB+)
unnamed: C62.1, D5.4, RN14.1, U28.3 (VINA+)
unnamed: R57.1, U28.1 (VOUTA), U28.2 (VINA-)
unnamed: R58.1, U28.6 (VINB-), U28.7 (VOUTB)
unnamed: R59.1, U28.8 (VOUTC), U28.9 (VINC-)
unnamed: R60.1, U28.13 (VIND-), U28.14 (VOUTD)

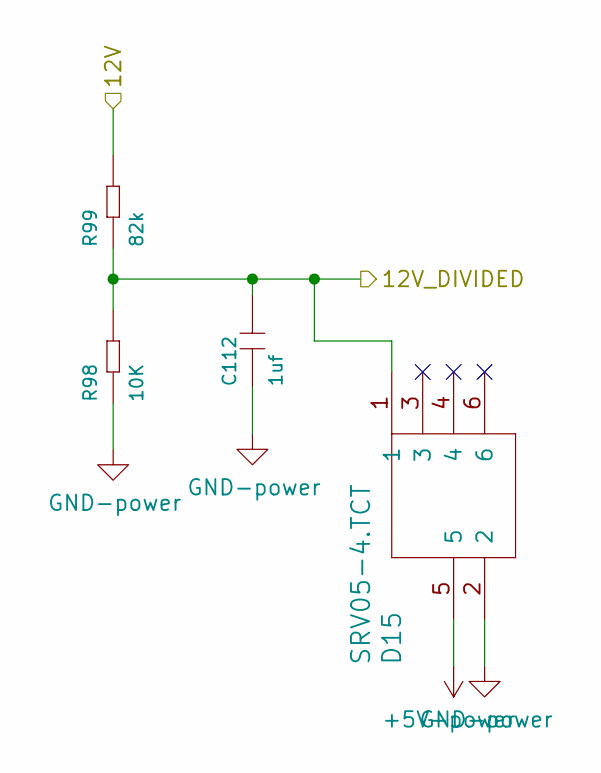
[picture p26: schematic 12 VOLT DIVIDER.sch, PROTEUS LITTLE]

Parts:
C112: 1uf; C0603
D15: SRV05-4.TCT; SOT95P280X145-6N
R98: 10K; R0603
R99: 82k; R0603

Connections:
+5V: D15.5; also elsewhere on the board
/12 VOLT DIVIDER/12V_DIVIDED: C112.2, D15.1, R98.2, R99.1; also elsewhere on the board
/12V: R99.2; also elsewhere on the board
GND: C112.1, D15.2, R98.1; also elsewhere on the board

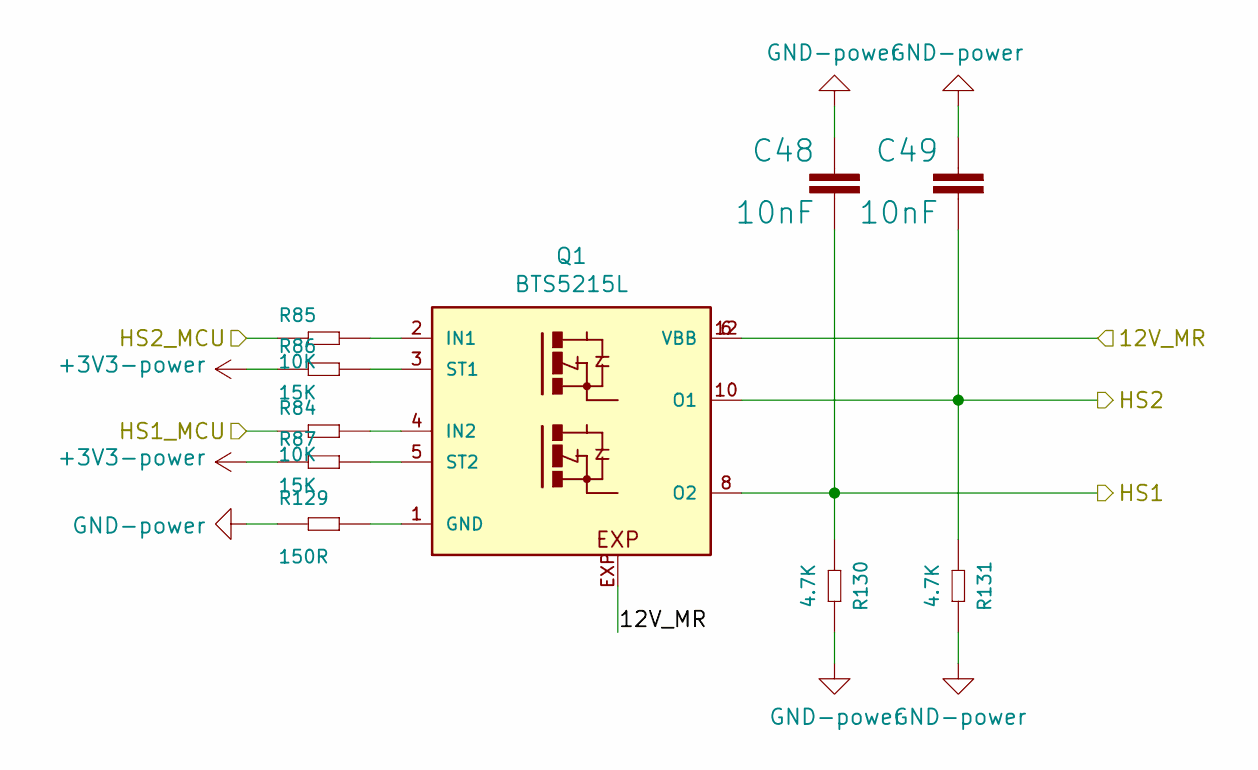
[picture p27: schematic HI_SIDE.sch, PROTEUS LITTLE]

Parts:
C48, C49: 10nF; 0603
Q1: BTS5215L; PG-DSO-12-9
R84, R85: 10K; R0402
R86, R87: 15K; R0402
R129: 150R; R0603
R130, R131: 4.7K; R0805

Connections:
+3V3: R86.1, R87.1; also elsewhere on the board
/12V_MR: Q1.6 (VBB), Q1.12 (VBB), Q1.EXP; also elsewhere on the board
/HI_SIDE/HS1_MCU: R84.1; also elsewhere on the board
/HI_SIDE/HS2_MCU: R85.1; also elsewhere on the board
/HS1: C48.2, Q1.8 (O2), R130.1; also elsewhere on the board
/HS2: C49.2, Q1.10 (O1), R131.1; also elsewhere on the board
GND: C48.1, C49.1, R129.1, R130.2, R131.2; also elsewhere on the board
unnamed: Q1.1 (GND), R129.2
unnamed: Q1.2 (IN1), R85.2
unnamed: Q1.3 (ST1), R86.2
unnamed: Q1.4 (IN2), R84.2
unnamed: Q1.5 (ST2), R87.2

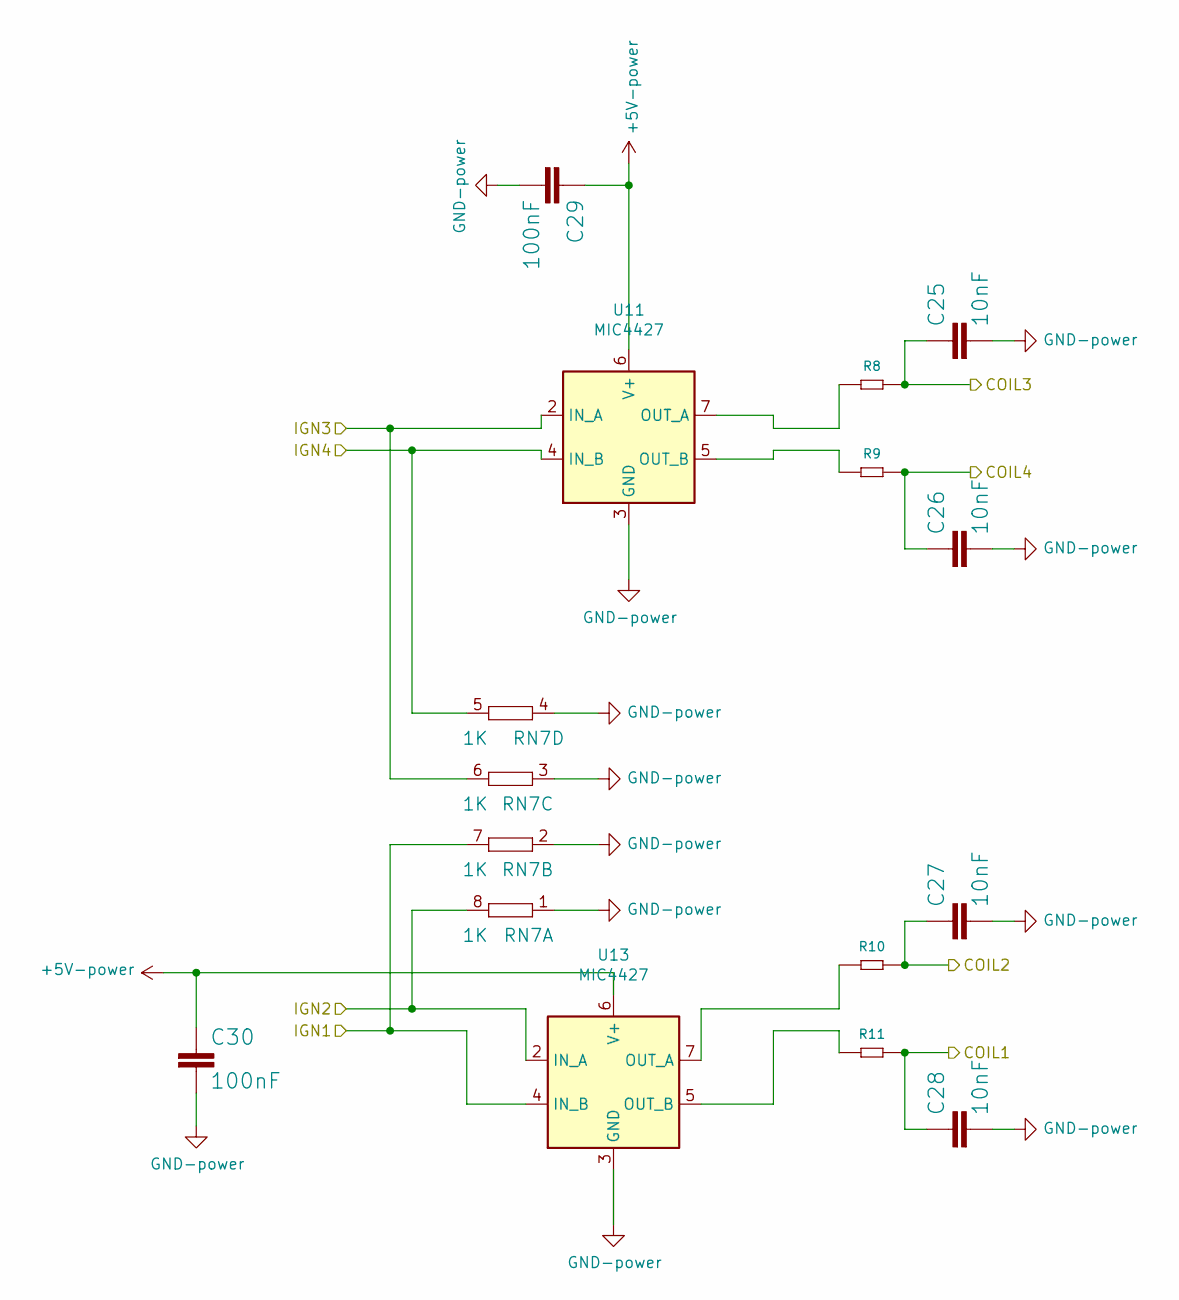
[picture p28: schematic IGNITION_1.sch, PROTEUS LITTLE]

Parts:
C25, C26, C27, C28: 10nF; 0603
C29, C30: 100nF; 0603
R8, R9, R10, R11: 100R; R0805
RN7: 1K; 0603-ARC
U11, U13: MIC4427; MSOP-8_3x3mm_P0.65mm

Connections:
+5V: C29.1, C30.1, U11.6 (V+), U13.6 (V+); also elsewhere on the board
/COIL1: C28.1, R11.2; also elsewhere on the board
/COIL2: C27.1, R10.2; also elsewhere on the board
/COIL3: C25.1, R8.2; also elsewhere on the board
/COIL4: C26.1, R9.2; also elsewhere on the board
/IGNITION_1/IGN1: RN7.7 (2), U13.4 (IN_B); also elsewhere on the board
/IGNITION_1/IGN2: RN7.8 (2), U13.2 (IN_A); also elsewhere on the board
/IGNITION_1/IGN3: RN7.6 (2), U11.2 (IN_A); also elsewhere on the board
/IGNITION_1/IGN4: RN7.5 (2), U11.4 (IN_B); also elsewhere on the board
GND: C25.2, C26.2, C27.2, C28.2, C29.2, C30.2, RN7.1, RN7.2 (1), RN7.3 (1), RN7.4 (1), U11.3 (GND), U13.3 (GND); also elsewhere on the board
unnamed: R8.1, U11.7 (OUT_A)
unnamed: R9.1, U11.5 (OUT_B)
unnamed: R10.1, U13.7 (OUT_A)
unnamed: R11.1, U13.5 (OUT_B)

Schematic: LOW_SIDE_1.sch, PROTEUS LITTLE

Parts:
C13, C14, C15, C16: 10nF; 0603
RN5, RN6: 1K; 0603-ARC
U7, U8: VNS3NV04DP-E; SOIC127P600X175-8N

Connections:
/LOW_SIDE_1/LS1_MCU: RN5.8 (2), RN6.5 (2); also elsewhere on the board
/LOW_SIDE_1/LS2_MCU: RN5.7 (2), RN6.6 (2); also elsewhere on the board
/LOW_SIDE_1/LS3_MCU: RN5.6 (2), RN6.7 (2); also elsewhere on the board
/LOW_SIDE_1/LS4_MCU: RN5.5 (2), RN6.8 (2); also elsewhere on the board
/LS1: C13.1, U8.5 (DRAIN2-1), U8.6 (DRAIN2); also elsewhere on the board
/LS2: C14.1, U8.7 (DRAIN1-1), U8.8 (DRAIN1); also elsewhere on the board
/LS3: C16.1, U7.5 (DRAIN2-1), U7.6 (DRAIN2); also elsewhere on the board
/LS4: C15.1, U7.7 (DRAIN1-1), U7.8 (DRAIN1); also elsewhere on the board
GND: C13.2, C14.2, C15.2, C16.2, RN6.1, RN6.2 (1), RN6.3 (1), RN6.4 (1), U7.1 (SOURCE1), U7.3 (SOURCE2), U8.1 (SOURCE1), U8.3 (SOURCE2); also elsewhere on the board
unnamed: RN5.1, U8.4 (INPUT2)
unnamed: RN5.2 (1), U8.2 (INPUT1)
unnamed: RN5.3 (1), U7.4 (INPUT2)
unnamed: RN5.4 (1), U7.2 (INPUT1)

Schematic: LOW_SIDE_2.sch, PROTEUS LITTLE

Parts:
C1, C2, C3, C8: 10nF; 0603
RN1, RN2: 1K; 0603-ARC
U2, U3: VNS3NV04DP-E; SOIC127P600X175-8N

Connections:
/LOW_SIDE_2/LS5_MCU: RN1.8 (2), RN2.5 (2); also elsewhere on the board
/LOW_SIDE_2/LS6_MCU: RN1.7 (2), RN2.6 (2); also elsewhere on the board
/LOW_SIDE_2/LS7_MCU: RN1.6 (2), RN2.7 (2); also elsewhere on the board
/LOW_SIDE_2/LS8_MCU: RN1.5 (2), RN2.8 (2); also elsewhere on the board
/LS5: C8.1, U2.5 (DRAIN2-1), U2.6 (DRAIN2); also elsewhere on the board
/LS6: C3.1, U2.7 (DRAIN1-1), U2.8 (DRAIN1); also elsewhere on the board
/LS7: C1.1, U3.5 (DRAIN2-1), U3.6 (DRAIN2); also elsewhere on the board
/LS8: C2.1, U3.7 (DRAIN1-1), U3.8 (DRAIN1); also elsewhere on the board
GND: C1.2, C2.2, C3.2, C8.2, RN2.1, RN2.2 (1), RN2.3 (1), RN2.4 (1), U2.1 (SOURCE1), U2.3 (SOURCE2), U3.1 (SOURCE1), U3.3 (SOURCE2); also elsewhere on the board
unnamed: RN1.1, U2.4 (INPUT2)
unnamed: RN1.2 (1), U2.2 (INPUT1)
unnamed: RN1.3 (1), U3.4 (INPUT2)
unnamed: RN1.4 (1), U3.2 (INPUT1)

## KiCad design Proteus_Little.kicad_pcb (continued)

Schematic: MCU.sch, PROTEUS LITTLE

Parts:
C4, C5, C82, C83, C84, C85, C86, C97, C99, C104, C109, C111: 10nf; C0603
C100, C101, C102, C103: 4.7uf; C0603
C105, C106: 2.2uf; C0603
C107, C108: 33pf; C0402
C110: 4.7uF; C0603
FB1: FERRITE_BEAD; BEADC2012X105N
R96, R97, R101, R102: 10K; R0603
SW1, SW2: SPST_TACT-KMR2; KMR2
U16: REF3033AIDBZR; SOT95P237X112-3N
U20: STM32F407ZGT6; STMICROELECTRONICS_STM32F429ZGT6_2
Y1: CRYSTAL_NX5032GA; CRYSTAL_2-SMD-5X3

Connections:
+3V3: C4.1, C5.1, C82.1, C83.1, C84.1, C85.1, C86.1, C97.1, C99.1, C100.1, C101.1, C102.1, C103.1, FB1.2, R96.1, R101.2, R102.2, SW2.1, SW2.3 (P1), U20.6 (VBAT), U20.17 (5_VDD), U20.30 (6_VDD), U20.39 (7_VDD), U20.52 (8_VDD), U20.62 (9_VDD), U20.72 (10_VDD), U20.84 (11_VDD), U20.95 (12_VDD), U20.108 (1_VDD), U20.121 (2_VDD), U20.131 (3_VDD), U20.143 (PDR_ON), U20.144 (4_VDD); also elsewhere on the board
+5V: U16.1 (IN); also elsewhere on the board
/12 VOLT DIVIDER/12V_DIVIDED: U20.43 (PA7); also elsewhere on the board
/ANALOG1/ANALOG1_MCU: U20.26 (PC0); also elsewhere on the board
/ANALOG1/ANALOG2_MCU: U20.27 (PC1); also elsewhere on the board
/ANALOG1/ANALOG3_MCU: U20.28 (PC2); also elsewhere on the board
/ANALOG1/ANALOG4_MCU: U20.29 (PC3); also elsewhere on the board
/ANALOG2/ANALOG5_MCU: U20.34 (PA0-WKUP(PA0)); also elsewhere on the board
/ANALOG2/ANALOG6_MCU: U20.35 (PA1); also elsewhere on the board
/ANALOG2/ANALOG7_MCU: U20.36 (PA2); also elsewhere on the board
/ANALOG2/ANALOG8_MCU: U20.37 (PA3); also elsewhere on the board
/ANALOG3/ANALOG9_MCU: U20.40 (PA4); also elsewhere on the board
/ANALOG3/ANALOG10_MCU: U20.41 (PA5); also elsewhere on the board
/ANALOG3/ANALOG11_MCU: U20.42 (PA6); also elsewhere on the board
/ANALOG_T/ANALOG_T1_MCU: U20.44 (PC4); also elsewhere on the board
/ANALOG_T/ANALOG_T2_MCU: U20.45 (PC5); also elsewhere on the board
/ANALOG_T/ANALOG_T3_MCU: U20.46 (PB0); also elsewhere on the board
/ANALOG_T/ANALOG_T4_MCU: U20.47 (PB1); also elsewhere on the board
/AUX_SPI_CS: U20.18 (PF6); also elsewhere on the board
/AUX_SPI_MISO: U20.20 (PF8); also elsewhere on the board
/AUX_SPI_MOSI: U20.21 (PF9); also elsewhere on the board
/AUX_SPI_SCK: U20.19 (PF7); also elsewhere on the board
/BARO/BARO_SCL: U20.69 (PB10); also elsewhere on the board
/BARO/BARO_SDA: U20.70 (PB11); also elsewhere on the board
/CAN/CAN1_RX: U20.114 (PD0); also elsewhere on the board
/CAN/CAN1_TX: U20.115 (PD1); also elsewhere on the board
/CAN/CAN2_RX: U20.73 (PB12); also elsewhere on the board
/CAN/CAN2_TX: U20.74 (PB13); also elsewhere on the board
/ETB/DIR: U20.79 (PD10); also elsewhere on the board
/ETB/DIS: U20.80 (PD11); also elsewhere on the board
/ETB/ETB_PWM: U20.81 (PD12); also elsewhere on the board
/HI_SIDE/HS1_MCU: U20.101 (PA9); also elsewhere on the board
/HI_SIDE/HS2_MCU: U20.100 (PA8); also elsewhere on the board
/IGNITION_1/IGN1: U20.118 (PD4); also elsewhere on the board
/IGNITION_1/IGN2: U20.117 (PD3); also elsewhere on the board
/IGNITION_1/IGN3: U20.99 (PC9); also elsewhere on the board
/IGNITION_1/IGN4: U20.98 (PC8); also elsewhere on the board
/IGNITION_2/IGN5: U20.97 (PC7); also elsewhere on the board
/IGNITION_2/IGN6: U20.93 (PG8); also elsewhere on the board
/IGNITION_2/IGN7: U20.92 (PG7); also elsewhere on the board
/IGNITION_2/IGN8: U20.91 (PG6); also elsewhere on the board
/INPUTS/CAM_VR_MCU: U20.59 (PE8); also elsewhere on the board
/INPUTS/CRANK_VR_MCU: U20.58 (PE7); also elsewhere on the board
/INPUTS/IN1_MCU: U20.96 (PC6); also elsewhere on the board
/INPUTS/IN2_MCU: U20.64 (PE11); also elsewhere on the board
/INPUTS/IN3_MCU: U20.65 (PE12); also elsewhere on the board
/INPUTS/IN4_MCU: U20.67 (PE14); also elsewhere on the board
/INPUTS/IN5_MCU: U20.66 (PE13); also elsewhere on the board
/INPUTS/IN6_MCU: U20.68 (PE15); also elsewhere on the board
/KNOCK_/FILTERED1: U20.14 (PF4); also elsewhere on the board
/KNOCK_/FILTERED2: U20.15 (PF5); also elsewhere on the board
/LED1: U20.2 (PE3); also elsewhere on the board
/LED2: U20.3 (PE4); also elsewhere on the board
/LED3: U20.4 (PE5); also elsewhere on the board
/LED4: U20.5 (PE6); also elsewhere on the board
/LOW_SIDE_1/LS1_MCU: U20.123 (PD7); also elsewhere on the board
/LOW_SIDE_1/LS2_MCU: U20.124 (PG9); also elsewhere on the board
/LOW_SIDE_1/LS3_MCU: U20.125 (PG10); also elsewhere on the board
/LOW_SIDE_1/LS4_MCU: U20.126 (PG11); also elsewhere on the board
/LOW_SIDE_2/LS5_MCU: U20.127 (PG12); also elsewhere on the board
/LOW_SIDE_2/LS6_MCU: U20.128 (PG13); also elsewhere on the board
/LOW_SIDE_2/LS7_MCU: U20.129 (PG14); also elsewhere on the board
/LOW_SIDE_2/LS8_MCU: U20.134 (PB4(NJTRST)); also elsewhere on the board
/LOW_SIDE_HIGH_CURRENT/LS11_MCU: U20.137 (PB7); also elsewhere on the board
/LOW_SIDE_HIGH_CURRENT/LS12_MCU: U20.139 (PB8); also elsewhere on the board
/LOW_SIDE_HIGH_CURRENT/LS13_MCU: U20.140 (PB9); also elsewhere on the board
/LOW_SIDE_HIGH_CURRENT/LS14_MCU: U20.141 (PE0); also elsewhere on the board
/MCU/D+: U20.104 (PA12); also elsewhere on the board
/MCU/D-: U20.103 (PA11); also elsewhere on the board
/MCU/SD_CS: U20.116 (PD2); also elsewhere on the board
/MCU/SD_MISO: U20.112 (PC11); also elsewhere on the board
/MCU/SD_MOSI: U20.113 (PC12); also elsewhere on the board
/MCU/SD_SCK: U20.111 (PC10); also elsewhere on the board
/RESET: C111.1, R96.2, SW1.1, SW1.3 (P1), U20.25 (NRST); also elsewhere on the board
/SWCLK: U20.109 (PA14(JTCK-SWCLK)); also elsewhere on the board
/SWDIO: U20.105 (PA13(JTMS-SWDIO)); also elsewhere on the board
/UART_RX: U20.119 (PD5); also elsewhere on the board
/UART_TX: U20.122 (PD6); also elsewhere on the board
GND: C4.2, C5.2, C82.2, C83.2, C84.2, C85.2, C86.2, C97.2, C99.2, C100.2, C101.2, C102.2, C103.2, C104.1, C105.1, C106.1, C107.2, C108.2, C109.1, C110.1, C111.2, R97.1, SW1.2 (S), SW1.4 (S1), U16.3 (GND), U20.16 (4_VSS), U20.31 (VSSA), U20.38 (5_VSS), U20.48 (PB2-BOOT1(PB2)), U20.51 (6_VSS), U20.61 (7_VSS), U20.83 (8_VSS), U20.94 (9_VSS), U20.107 (1_VSS), U20.120 (2_VSS), U20.130 (3_VSS); also elsewhere on the board
unnamed: C104.2, U16.2 (OUT), U20.32 (VREF+)
unnamed: C105.2, U20.71 (VCAP_1)
unnamed: C106.2, U20.106 (VCAP_2)
unnamed: C107.1, U20.24 (PH1-OSC_OUT(PH1)), Y1.1
unnamed: C108.1, U20.23 (PH0-OSC_IN(PH0)), Y1.2
unnamed: C109.2, C110.2, FB1.1, U20.33 (VDDA)
unnamed: R97.2, SW2.2 (S), SW2.4 (S1), U20.138 (BOOT0)
unnamed: R101.1, U20.8 (PC14-OSC32_IN(PC14))
unnamed: R102.1, U20.9 (PC15-OSC32_OUT(PC15))

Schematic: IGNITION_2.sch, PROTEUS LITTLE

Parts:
C31, C32, C33, C34: 10nF; 0603
C35, C36: 100nF; 0603
R12, R13, R14, R15: 100R; R0805
R1020, R1021, R1022: 330R; R0805
R1023: 330r; R0805
RN8: 1K; 0603-ARC
U14, U15: MIC4427; MSOP-8_3x3mm_P0.65mm
U32, U33, U34, U35: ISL9V3040D3STV; TO229P990X238-4N

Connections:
+5V: C35.1, C36.1, U14.6 (V+), U15.6 (V+); also elsewhere on the board
/COIL5: C33.1, R14.2, U33.4 (EMITTER); also elsewhere on the board
/COIL6: C34.1, R15.2, U32.4 (EMITTER); also elsewhere on the board
/COIL7: C31.1, R12.2, U35.4 (EMITTER); also elsewhere on the board
/COIL8: C32.1, R13.2, U34.4 (EMITTER); also elsewhere on the board
/IGNITION_2/IGN5: RN8.8 (2), U15.2 (IN_A); also elsewhere on the board
/IGNITION_2/IGN6: RN8.7 (2), U15.4 (IN_B); also elsewhere on the board
/IGNITION_2/IGN7: RN8.6 (2), U14.2 (IN_A); also elsewhere on the board
/IGNITION_2/IGN8: RN8.5 (2), U14.4 (IN_B); also elsewhere on the board
GND: C31.2, C32.2, C33.2, C34.2, C35.2, C36.2, RN8.1, RN8.2 (1), RN8.3 (1), RN8.4 (1), U14.3 (GND), U15.3 (GND), U32.3 (COLLECTOR), U33.3 (COLLECTOR), U34.3 (COLLECTOR), U35.3 (COLLECTOR); also elsewhere on the board
unnamed: R1020.1, U32.1 (GATE)
unnamed: R15.1, R1020.2, U15.5 (OUT_B)
unnamed: R14.1, R1021.1, U15.7 (OUT_A)
unnamed: R1021.2, U33.1 (GATE)
unnamed: R1022.1, U34.1 (GATE)
unnamed: R13.1, R1022.2, U14.5 (OUT_B)
unnamed: R1023.1, U35.1 (GATE)
unnamed: R12.1, R1023.2, U14.7 (OUT_A)

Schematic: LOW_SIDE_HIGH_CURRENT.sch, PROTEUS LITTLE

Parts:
C9, C10, C11, C12: 10nF; 0603
C125: 100nF; 0603
D16, D17, D20, D21: MBR0520LT1G; SOD-123FL
R138, R139, R140, R141: 10K; R0603
RN3, RN4: 1K; 0603-ARC
U5, U6: VNLD5090TR-E; SOIC-8_3.9x4.9mm_P1.27mm
U36: 74HC125DB,112; SOP65P775X265-14N

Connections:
+5V: C125.2, U36.14 (VCC); also elsewhere on the board
/12V_MR: D16.C, D17.C, D20.C, D21.C; also elsewhere on the board
/LOW_SIDE_HIGH_CURRENT/LS11_BUFF: RN3.8 (2), RN4.5 (2), U36.11 (4Y)
/LOW_SIDE_HIGH_CURRENT/LS11_MCU: R138.1, U36.12 (4A); also elsewhere on the board
/LOW_SIDE_HIGH_CURRENT/LS12_BUFF: RN3.7 (2), RN4.6 (2), U36.8 (3Y)
/LOW_SIDE_HIGH_CURRENT/LS12_MCU: R139.1, U36.9 (3A); also elsewhere on the board
/LOW_SIDE_HIGH_CURRENT/LS13_BUFF: RN3.6 (2), RN4.7 (2), U36.6 (2Y)
/LOW_SIDE_HIGH_CURRENT/LS13_MCU: R140.1, U36.5 (2A); also elsewhere on the board
/LOW_SIDE_HIGH_CURRENT/LS14_BUFF: RN3.5 (2), RN4.8 (2), U36.3 (1Y)
/LOW_SIDE_HIGH_CURRENT/LS14_MCU: R141.1, U36.2 (1A); also elsewhere on the board
/LS11: C9.1, D21.A, U6.6 (DRAIN2); also elsewhere on the board
/LS12: C10.1, D20.A, U6.8 (DRAIN1); also elsewhere on the board
/LS13: C12.1, D17.A, U5.6 (DRAIN2); also elsewhere on the board
/LS14: C11.1, D16.A, U5.8 (DRAIN1); also elsewhere on the board
GND: C9.2, C10.2, C11.2, C12.2, C125.1, R138.2, R139.2, R140.2, R141.2, RN4.1, RN4.2 (1), RN4.3 (1), RN4.4 (1), U5.5 (SOURCE2), U5.7 (SOURCE1), U6.5 (SOURCE2), U6.7 (SOURCE1), U36.1 (1OE), U36.4 (2OE), U36.7 (GND), U36.10 (3OE), U36.13 (4OE); also elsewhere on the board
unnamed: RN3.1, U6.3 (IN2)
unnamed: RN3.2 (1), U6.1 (IN1)
unnamed: RN3.3 (1), U5.3 (IN2)
unnamed: RN3.4 (1), U5.1 (IN1)

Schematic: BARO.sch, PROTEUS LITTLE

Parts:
C20: 100nF; 0603
C119, C120: 1.0uF; 0603
R32, R95: 2.2K; R0603
U9: LPS25HBTR; PQFN60P250X250X80-10N
U26: MPXAZ6115A; Freescale_98ARH99066A

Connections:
+3V3: C20.1, R32.1, R95.2, U9.1 (VDD_IO), U9.6 (CS), U9.10 (VDD); also elsewhere on the board
+5V: C119.1, C120.1, U26.2 (Vcc); also elsewhere on the board
/ANALOG9: U26.4 (Vout); also elsewhere on the board
/BARO/BARO_SCL: R95.1, U9.2 (SCL/SPC); also elsewhere on the board
/BARO/BARO_SDA: R32.2, U9.4 (SDA/SDI/SDO); also elsewhere on the board
GND: C20.2, C119.2, C120.2, U9.3 (RES), U9.5 (SDO/SA0), U9.8 (GND), U9.9 (GND), U26.3 (GND); also elsewhere on the board

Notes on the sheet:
BARO SENSOR

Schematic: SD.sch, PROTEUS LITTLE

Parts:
J2: 47219-2001; MOLEX_47219-2001

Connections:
+3V3: J2.4 (VDD); also elsewhere on the board
/MCU/SD_CS: J2.2 (CD/DAT3); also elsewhere on the board
/MCU/SD_MISO: J2.7 (DAT0); also elsewhere on the board
/MCU/SD_MOSI: J2.3 (CMD); also elsewhere on the board
/MCU/SD_SCK: J2.5 (CLK); also elsewhere on the board
GND: J2.6 (VSS), J2.G1 (GND@1), J2.G2 (GND@2), J2.G3 (GND@3), J2.G4 (GND@4); also elsewhere on the board

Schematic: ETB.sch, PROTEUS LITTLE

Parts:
C39, C40: 10nF; 0603
C41: 56uF; E3,5-8
C113: 10uf; C1206
R22: 10K; R0603
U10: TLE9201SG; SOP100P1030X260-13N

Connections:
+3V3: R22.2, U10.2 (VSO); also elsewhere on the board
/12V_MR: C41.+, C113.1, U10.4 (VS); also elsewhere on the board
/ETB/DIR: U10.1 (DIR); also elsewhere on the board
/ETB/DIS: R22.1, U10.11 (DIS); also elsewhere on the board
/ETB/ETB_PWM: U10.12 (PWM); also elsewhere on the board
/OUT+: C39.2, U10.5 (OUT1); also elsewhere on the board
/OUT-: C40.1, U10.7 (OUT2); also elsewhere on the board
GND: C39.1, C40.2, C41.-, C113.2, U10.6 (GND@1), U10.13 (GND@2); also elsewhere on the board

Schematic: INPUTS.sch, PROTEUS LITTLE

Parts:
C7, C17, C18, C21, C22, C23, C24, C50, C51, C55, C63, C64, C65, C66: 1nF; 0603
C52: 100nF; 0603
C53: 1.0uF; 0603
C54: 10nF; 0603
R1, R48, R49, R50, R76, R77: 10K; R0805
R2, R3, R4, R26, R27, R44: 2.2K; R0603
R5, R6, R7, R28, R29, R45: 3.3K; R0603
S1, S3: JS202011SCQN; SW_JS202011SCQN
U12, U18, U31: 74HC2G17; SOP65P210X110-6N
U19: MAX9926UAEE+; SOP63P602X175-16N

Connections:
+3V3: R1.2, R50.2; also elsewhere on the board
+5V: C52.2, C53.1, C54.2, U12.5 (VCC), U18.5 (VCC), U19.14 (VCC), U31.5 (VCC); also elsewhere on the board
/5V_SENSORS: R2.1, R3.1, R4.2, R26.1, R27.2, R44.1; also elsewhere on the board
/CAM+: S3.2, S3.5; also elsewhere on the board
/CAM-: R48.2; also elsewhere on the board
/CRANK+: S1.2, S1.5; also elsewhere on the board
/CRANK-: R76.2; also elsewhere on the board
/IN1: C65.2, R27.1, R29.1; also elsewhere on the board
/IN4: C21.2, R4.1, R6.1; also elsewhere on the board
/IN5: C17.2, R3.2, R5.1; also elsewhere on the board
/IN6: C63.2, R26.2, R28.1; also elsewhere on the board
/INPUTS/CAM+HALL: C23.2, R2.2, R7.1, S3.1, S3.4
/INPUTS/CAM+VR: R49.2, S3.3, S3.6
/INPUTS/CAM_IN: C24.2, R7.2, U18.3 (2A)
/INPUTS/CAM_VR_MCU: R50.1, U19.5 (COUT2); also elsewhere on the board
/INPUTS/CRANK+HALL: C50.2, R44.2, R45.1, S1.1, S1.4
/INPUTS/CRANK+VR: R77.2, S1.3, S1.6
/INPUTS/CRANK_IN: C51.2, R45.2, U18.1 (1A)
/INPUTS/CRANK_VR_MCU: R1.1, U19.4 (COUT1); also elsewhere on the board
/INPUTS/IN1_IN: C66.1, R29.2, U31.1 (1A)
/INPUTS/IN1_MCU: U31.6 (1Y); also elsewhere on the board
/INPUTS/IN2_MCU: U18.4 (2Y); also elsewhere on the board
/INPUTS/IN3_MCU: U18.6 (1Y); also elsewhere on the board
/INPUTS/IN4_IN: C22.1, R6.2, U12.1 (1A)
/INPUTS/IN4_MCU: U12.6 (1Y); also elsewhere on the board
/INPUTS/IN5_IN: C18.2, R5.2, U12.3 (2A)
/INPUTS/IN5_MCU: U12.4 (2Y); also elsewhere on the board
/INPUTS/IN6_IN: C64.2, R28.2, U31.3 (2A)
/INPUTS/IN6_MCU: U31.4 (2Y); also elsewhere on the board
GND: C17.1, C18.1, C21.1, C22.2, C23.1, C24.1, C50.1, C51.1, C52.1, C53.2, C54.1, C63.1, C64.1, C65.1, C66.2, U12.2 (GND), U18.2 (GND), U19.1 (INT_THRS1), U19.3 (BIAS1), U19.6 (BIAS2), U19.8 (INT_THRS2), U19.11 (GND), U19.13 (ZERO_EN), U31.2 (GND); also elsewhere on the board
unnamed: C7.1, R77.1, U19.16 (IN1+)
unnamed: C7.2, R76.1, U19.15 (IN1-)
unnamed: C55.1, R49.1, U19.9 (IN2+)
unnamed: C55.2, R48.1, U19.10 (IN2-)

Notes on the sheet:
VR_SENSOR
HALL SENSORS
SEL_SWITCH

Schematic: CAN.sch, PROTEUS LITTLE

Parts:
C6, C123: 1.0uF; 0603
C19, C124: 100nF; 0603
D4, D19: PESD1CAN; SOT23
R40, R137: 10K; R0603
R41, R136: 120R; R0603
U27, U30: VD230; SO08; LCSC C146561

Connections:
+3V3: C6.1, C19.1, C123.1, C124.1, U27.3 (VCC), U30.3 (VCC); also elsewhere on the board
/CAN1H: D4.2, R41.2, U27.7 (CANH); also elsewhere on the board
/CAN1L: D4.1, R41.1, U27.6 (CANL); also elsewhere on the board
/CAN2H: D19.2, R136.2, U30.7 (CANH); also elsewhere on the board
/CAN2L: D19.1, R136.1, U30.6 (CANL); also elsewhere on the board
/CAN/CAN1_RX: U27.4 (R); also elsewhere on the board
/CAN/CAN1_TX: U27.1 (D); also elsewhere on the board
/CAN/CAN2_RX: U30.4 (R); also elsewhere on the board
/CAN/CAN2_TX: U30.1 (D); also elsewhere on the board
GND: C6.2, C19.2, C123.2, C124.2, D4.3, D19.3, R40.1, R137.1, U27.2 (GND), U30.2 (GND); also elsewhere on the board
unnamed: R40.2, U27.8 (RS)
unnamed: R137.2, U30.8 (RS)

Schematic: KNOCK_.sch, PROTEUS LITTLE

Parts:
C42, C67: 3.3nf; C0805
C73, C74: 680pf; C0603
C75, C76: 47PF; C0402
C77, C78: 330PF 50V; C0402
C79: 10nf; C0402
C80, C81: 10uf; C0805
J5: AudioJack3; Jack_3.5mm_CUI_SJ1-3533NG_Horizontal
R33, R46: 12K; R0402
R51, R61, R62, R63: 100K; R0402
R64, R81: 22K; R0402
R82, R83: 33K; R0402
R93, R94: 470K; R0402
U25: MCP6004-E_SL; SOIC127P600X175-14N
U$1: MCP6002-E_SN; SOIC127P599X175-8N

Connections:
+3V3: R64.2, U25.4 (VDD); also elsewhere on the board
+5V: U$1.8 (VDD); also elsewhere on the board
/KNOCK1: C42.1; also elsewhere on the board
/KNOCK2: C67.1; also elsewhere on the board
/KNOCK_/FILTERED1: C77.2, U25.6 (VINB-), U25.7 (VOUTB), U$1.2 (VINA-); also elsewhere on the board
/KNOCK_/FILTERED2: C78.1, U25.8 (VOUTC), U25.9 (VINC-), U$1.6 (VINB-); also elsewhere on the board
GND: C73.2, C74.1, C75.2, C76.1, C79.2, J5.S, R81.1, U25.11 (VSS), U$1.4 (VSS); also elsewhere on the board
unnamed: C42.2, R51.1
unnamed: C67.2, R61.1
unnamed: C73.1, R33.2, R62.1
unnamed: C74.2, R46.2, R63.1
unnamed: C75.1, R82.2, U25.5 (VINB+)
unnamed: C76.2, R83.2, U25.10 (VINC+)
unnamed: C77.1, R62.2, R82.1
unnamed: C78.2, R63.2, R83.1
unnamed: C79.1, R64.1, R81.2, U25.3 (VINA+), U25.12 (VIND+)
unnamed: C80.1, U$1.5 (VINB+), U$1.7 (VOUTB)
unnamed: C80.2, J5.R
unnamed: C81.1, U$1.1 (VOUTA), U$1.3 (VINA+)
unnamed: C81.2, J5.T
unnamed: R33.1, R93.2, U25.1 (VOUTA)
unnamed: R46.1, R94.2, U25.14 (VOUTD)
unnamed: R51.2, R93.1, U25.2 (VINA-)
unnamed: R61.2, R94.1, U25.13 (VIND-)

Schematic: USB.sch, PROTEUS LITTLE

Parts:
C114: 100nf; 0603
D10: USBLC6-2SC6; SOT95P280X145-6N
D22: MBR0520LT1G; SODFL3718X115
J6: USB_B_Micro; USB_Micro-B_Wuerth_614105150721_Vertical
J9: Conn_01x04_Female; PinHeader_1x04_P2.54mm_Vertical
R100: 100K; R0402

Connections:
+5V: D22.1 (C); also elsewhere on the board
/MCU/D+: D10.1 (I/O1), D10.6 (I/O1), J6.3 (D+), J9.3; also elsewhere on the board
/MCU/D-: D10.3 (I/O2), D10.4 (I/O2), J6.2 (D-), J9.2; also elsewhere on the board
/USB/SHIELD: C114.1, J6.6 (Shield), R100.2
GND: C114.2, D10.2 (GND), J6.5 (GND), J9.4, R100.1; also elsewhere on the board
unnamed: D10.5 (VBUS), D22.2 (A), J6.1 (VBUS), J9.1

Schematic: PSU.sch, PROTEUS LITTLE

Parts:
C38: 4.7uF; 0603
C87: 10nF; 0603
C88: 100nF; 0603
C89: 270PF; 0603
C90, C93: 10uf; C1206
C91: 56uF; E3,5-8
C92, C95, C96: 1.0uF; 0603
C94: 4.7uF; 0603; LCSC C329940
C98: 22uf; 0603
D3: SM15T33CA; DIOM7959X262N; LCSC C133707
D12: C8678; SMA-DIODE
D13: C8678; SMA-DIODE; LCSC C85098
L2: 10U; 0503
L3: 2.2U; L3225M
R47: B72530T6170K062; R-5
R88: 10K; R0603
R89: 1R; R0603; LCSC C22936
R90: 12K; R0402
R91: 68K; R0603
U21: TLE4251DATMA1; TO114P998X235-5
U23: LMR14020SDDAR; VREG_LM5017MR_NOPB
U29: AMS1117-3.3; SOT229P700X180-4N

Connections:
+3V3: C38.2, U29.2 (VOUT), U29.4 (VOUT); also elsewhere on the board
+5V: C89.2, C90.1, C93.1, L2.P$2 (2), R91.2, U21.4 (ADJ), U29.3 (VIN); also elsewhere on the board
/5V_SENSORS: C95.2, C98.2, U21.5 (Q); also elsewhere on the board
/12V: C96.2, D3.1, D13.A, R47.1, U21.1 (I), U21.2 (EN); also elsewhere on the board
GND: C38.1, C87.2, C90.2, C91.-, C92.2, C93.2, C94.2, C95.1, C96.1, C98.1, D3.2, D12.A, R47.2, R88.1, R90.2, U21.3 (GND), U23.7 (GND), U23.9 (THERMALPAD), U29.1 (ADJ/GND); also elsewhere on the board
unnamed: C87.1, U23.6 (SS)
unnamed: C88.1, U23.1 (BOOT)
unnamed: C88.2, D12.C, L2.P$1 (1), U23.8 (SW)
unnamed: C89.1, R90.1, R91.1, U23.5 (FB)
unnamed: C91.+, C92.1, L3.2, U23.2 (VIN), U23.3 (EN)
unnamed: C94.1, R89.2
unnamed: D13.C, L3.1, R89.1
unnamed: R88.2, U23.4 (RT/SYNC)

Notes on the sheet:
5V SENSOR

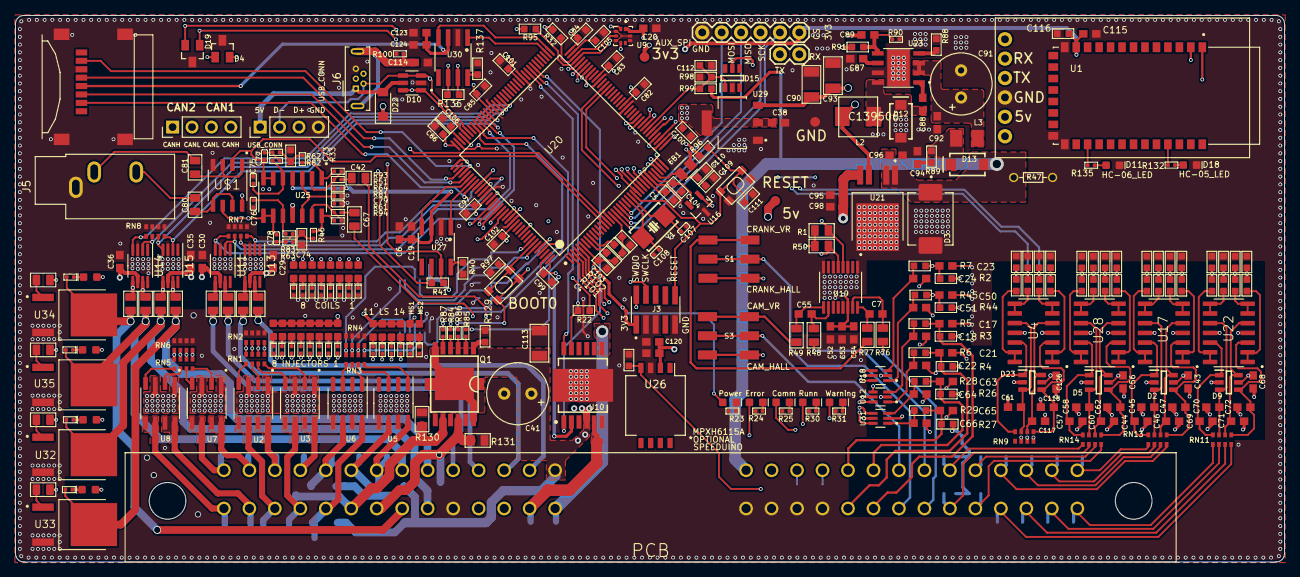
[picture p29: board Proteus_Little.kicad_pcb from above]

Board: 4 copper layers, 166.0 x 71.5 mm, 394 parts (0 on the bottom side), 288 nets.
